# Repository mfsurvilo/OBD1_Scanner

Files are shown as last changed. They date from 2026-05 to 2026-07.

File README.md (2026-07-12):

# OBD1 Scanner

An ESP32-S3 based scanner for OBD-I era ECUs. The device hosts its own Wi-Fi
access point and serves a web console (PWA) straight off the chip — no app to
install — and updates itself over the internet with one button.

- **Firmware:** Arduino/ESP32-S3 (PlatformIO), FreeRTOS tasks, AP+STA Wi-Fi,
  OTA with bootloader rollback.
- **Console (PWA):** served from the device's LittleFS partition; live status
  over WebSocket, Wi-Fi provisioning, one-button update.
- **Delivery:** GitHub Releases hold the images; a static GitHub Pages page
  flashes a device over USB for recovery.

## How the pieces fit together

```
  ┌────────────┐   serves    ┌──────────────┐
  │  firmware  │ ──────────▶ │  PWA console │   (pwa_app/, flashed into LittleFS)
  │  (obd1)    │             │  obd1.local  │
  └─────┬──────┘             └──────┬───────┘
        │ heartbeat + /status       │ "Update now"
        │                           ▼
        │                    GET /update/check   ── picks highest release version
        │                    POST /update/pull   ── pulls firmware.bin + filesystem.bin
        ▼                                            from that release, flashes both
  GitHub Releases  ◀── build_release.sh / release.yml (firmware.bin, filesystem.bin, factory.bin)
        ▲
        │ mirrors factory.bin
  GitHub Pages flasher (firmware_server/flasher/)  ── USB recovery, version dropdown
```

Single sources of truth: `pwa_app/` is the only copy of the console, and
`firmware_server/flasher/versions.json` is the only list of published versions.

## Repo layout

| Path | What it is |
|---|---|
| `firmware/` | PlatformIO project — the device firmware, build/upload scripts, on-target tests |
| `pwa_app/` | The web console served from the device (flashed as the LittleFS image) |
| `firmware_server/` | The static USB-recovery flasher (GitHub Pages) — see its [README](firmware_server/README.md) |
| `tests/` | Host contract tests + hardware-in-the-loop scripts — see its [README](tests/README.md) |
| `protocol/`, `PROTOCOL.md` | OBD-I protocol notes |
| `board/` | KiCad hardware design |
| `developer_tools/` | Misc developer utilities |
| `CHANGELOG.md` | Per-version changes, split into Firmware / PWA sections |

## Quick start

**Flash a board over USB (developer):**
```bash
cd firmware && ./upload.sh          # builds + flashes firmware and the PWA image
```

**Use the device:** join Wi-Fi `OBD1_Scanner` (password `subaru92`), then open
`http://obd1.local/` (or `http://192.168.4.1/`).

## Flashing — three ways

1. **Developer USB** — `firmware/upload.sh` (one combined `pio` command: app + LittleFS).
2. **End-user USB recovery** — the GitHub Pages flasher: pick a version, connect,
   and flash the full image over WebSerial (desktop Chrome/Edge/Opera).
3. **Over-the-air** — the console's **Update now** button (details below).

## Updates (OTA)

The device updates itself over your home Wi-Fi — no file downloads:

1. In the console, save your home Wi-Fi credentials (**Internet update**).
2. Hit **Update now**. The firmware lists the repo's releases, picks the
   **highest version number** (it does *not* rely on GitHub's date-ordered
   `/releases/latest`), and pulls that release's `firmware.bin` (app) and
   `filesystem.bin` (PWA) by explicit tag.
3. It flashes both and reboots. A freshly-updated image boots on probation and
   must self-confirm healthy; if it doesn't, the bootloader rolls back to the
   previous slot.

## Releases

Each release publishes three stable-named assets (the git **tag** carries the
version): `firmware.bin` (app, OTA), `filesystem.bin` (PWA, OTA), and
`factory.bin` (full flash, USB recovery).

To cut a release:
```bash
git tag v0.5 && git push origin v0.5      # release.yml builds + publishes the assets
```
Then add the version to `firmware_server/flasher/versions.json` (newest first,
`latest: true` on it) and push to `master` so the Pages flasher lists it.

Full details — asset layout, the Pages CORS mirror, and the CI workflows — are
in **[`firmware_server/README.md`](firmware_server/README.md)**.

> Tip: cut and push one release tag at a time. Pushing a tag and a `master`
> change together can race the `release` and `pages` workflows.

## Testing

| Layer | What | Runs in CI? |
|---|---|---|
| 0 — host contract (`pytest`) | partition layout, `/status` + `/update/*` surface, image sizes, release-asset & `versions.json` contracts | ✅ |
| 1 — native unit (`pio test -e native`) | pure firmware logic — semver version ordering | ✅ |
| 4–5 — hardware (`hil_roundtrip.py`) | OTA app+fs round-trip, rollback, downgrade matrix | ❌ manual/local |

```bash
python -m pytest tests/ -q          # Layer 0, no hardware (what CI runs)
cd firmware && pio test -e native   # Layer 1, native Unity tests
```

Hardware tests need a real board on the `OBD1_Scanner` AP with USB attached.
Full commands and modes are in **[`tests/README.md`](tests/README.md)**.

## Building

```bash
cd firmware
./upload.sh                # build + USB-flash app + PWA
./build_release.sh         # build + package firmware.bin / filesystem.bin / factory.bin
pio run -e obd1            # just compile the firmware
```
Requires PlatformIO and `esptool` (both in the project `venv/`).

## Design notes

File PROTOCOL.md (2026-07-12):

# OBD1 Scanner — FW ↔ Front-End Protocol

**Protocol version: 1** · Status: living document · Last updated 2026-07-01

This is the single source of truth for the contract between the ESP32 firmware
(`firmware/`) and any front end (`pwa_app/`, `flask_app/`, future UIs). If the
firmware and a UI disagree, they disagree with *this file* — fix the doc and
both sides, don't quietly diverge.

## The value pipeline

```
raw byte ──[FW: hardcoded formula]──▶ engineering ──[app: user calibration]──▶ displayed
             engineering = raw·hw_scale + hw_offset      displayed = engineering·cal_slope + cal_offset
```

- **Hardcoded formula** (`hw_scale`, `hw_offset`) — a fixed property of the SSM1
  protocol per parameter (e.g. `rpm = raw·25`, `°F = raw·1.8 − 147.6`). Baked
  into firmware in `ecu_defs.h` as the `paramMappings[]` table, keyed by name and
  shared across all ECU tables. **Not user-editable.** Source:
  `resources/possible_mapping.txt`. The FW applies this and streams the
  **engineering** value as `params[].value` (and `raw` alongside).
- **User calibration** (`cal_slope` default 1, `cal_offset` default 0) — a trim
  the user applies on top, per parameter. Persisted in FW flash
  (`scaling_config.*`; the NVS keys are still `multiplier`/`offset`). **Applied
  by the app**, not the FW — so tuning is instant and doesn't wear flash. Defaults
  are a no-op, so gauges read correct engineering units out of the box.
- **Poll factor** — the weighted-round-robin poll weight (0 = off). User-editable
  and persisted per param (alongside calibration). On save the FW pushes it to
  the live scheduler; on boot it seeds from the stored value (else a poll-tier
  default).

## Ownership split

| Concern | Owner | Persisted where |
|---|---|---|
| **Hardcoded formula** — `hw_scale`, `hw_offset`, `unit` per param | **Firmware (fixed)** | compiled in `ecu_defs.h` (`paramMappings[]`) |
| **User calibration** — `cal_slope`, `cal_offset` | **User sets; FW stores; app applies** | ESP32 flash (`scaling_config.*`) |
| **Poll factor** — per-param weight (0 = off) | **User sets; FW stores + runs** | ESP32 flash + live scheduler |
| **Presentation** — display label, min/max range, grouping | **Front end** | client-side (localStorage) |

---

## Transports

| Purpose | Transport | Address |
|---|---|---|
| The PWA itself (HTML/CSS/JS/icons) | HTTP GET | `http://<host>/` — served from ESP LittleFS |
| Live data stream (primary) | WebSocket | `ws://<host>:81/` — **root path, no `/ws` suffix** |
| Snapshot poll (fallback) | HTTP GET | `http://<host>:80/data` |
| Calibration / logs / control | HTTP | `http://<host>:80/...` |

`<host>` is `192.168.4.1` (SoftAP `OBD1_Scanner`) or `obd1.local` (mDNS). The
scanner is **AP-only** — the phone connects straight to its access point and
loads the PWA from the device; there is no home-WiFi/station mode.

> ⚠️ **Known drift to fix (2026-07-01):** the current PWA connects to
> `ws://…:<port>/ws` (`pwa_app/js/app.js:378`) and its settings default the port
> to `81` in JS but show `80` in the HTML input (`index.html:262`). Per this
> spec the WS is **port 81, path `/`**. New UI must follow the spec.

---

## Downstream: data snapshot (FW → UI)

The firmware maintains one JSON snapshot and (a) broadcasts it over the
WebSocket whenever it changes, and (b) serves the latest copy at `GET /data`.
On WS connect the current snapshot is sent immediately so the UI populates
without waiting for the next change.

### Schema

```jsonc
{
  "connected": true,          // bool — FW believes it is talking to the ECU
  "timestamp": 123456,        // uint — millis() of last data change (FW uptime)
  "params": [                 // array — one entry per param currently served
    {
      "name":  "EngineSpeed", // string — stable catalog key (see /params)
      "raw":   128,           // number — the ECU byte, before any conversion
      "value": 3200,          // number — ENGINEERING value = raw·hw_scale + hw_offset (FW-applied)
      "unit":  "rpm",         // string — engineering unit
      "time":  123450         // uint   — millis() this param was last read
      // The app shows: value·cal_slope + cal_offset (user calibration, app-applied).
    }
  ],
  "baseHz": 12.5,             // number — est. Hz for a factor-1 param (see polling model)
  "dtc": [                    // array — present only once DTCs are reported
    { "type": "active", "code": "21", "desc": "Coolant temp sensor" }
  ],
  "status": "..."             // string — optional human-readable status line
}
```

Notes:
- `params` is keyed by `name` on both sides. **Never** index by array position.
- `raw` is the ECU value pre-scaling. The UI computes the displayed value as
  `raw * scale + offset` using the calibration for that `name` (from `/params`).
  The wire never carries a pre-scaled `value` — see "Persist ≠ apply" above.
- `params` contains only params whose active `factor > 0`. A param set to 0 is
  absent from the snapshot, not present with a stale value.
- `dtc[].type` ∈ `"active" | "stored"`. `code` is the Subaru 2-digit code as a
  string; `desc` is human text.
- A UI must tolerate unknown `name`s and missing optional keys (`dtc`, `status`).

### Parameter catalog (active ECU: `7232A5` — 1992 UK Legacy EJ22)

These are the `name`s the firmware can currently produce (from `ecu_defs.h`).
Units below are the **firmware default**; the UI owns display range/label.

| name | default unit | poll tier |
|---|---|---|
| EngineSpeed | rpm | fast (50 ms) |
| VehicleSpeed | mph/km/h | fast |
| ThrottlePosition | % | medium (100 ms) |
| O2Average | V | medium |
| IgnitionAdvance | ° BTDC | medium |
| EngineLoad | % | medium |
| InjectorPulseWidth | ms | medium |
| KnockCorrection | ° | medium |
| AFCorrection | % | medium |
| BatteryVoltage | V | slow (250 ms) |
| CoolantTemp | °F/°C | slow |
| AirflowSensor | — | slow |
| ISUDutyValve | % | slow |
| AtmosphericPressure | kPa | vslow (500 ms) |
| InputSwitches | bitfield | vslow |
| IOSwitches | bitfield | vslow |

> The catalog changes with the selected ECU (`#define ECU_*` in `ecu_defs.h`).
> UIs should not hardcode this list — read it from `GET /params` (below).

---

## The parameter record

`GET /params` returns one record per param for the active ECU, combining the
fixed hardcoded mapping with the user-editable calibration:

| field | type | editable? | meaning |
|---|---|---|---|
| `name` | string | no | stable catalog key, e.g. `"EngineSpeed"` |
| `addr` | string | no | ECU memory address, e.g. `"0x1338"` |
| `unit` | string | no | engineering unit, e.g. `"rpm"` |
| `hw_scale` | number | no | hardcoded formula multiplier (`paramMappings[]`) |
| `hw_offset` | number | no | hardcoded formula offset |
| `cal_slope` | number | **yes** (default 1) | user calibration multiplier |
| `cal_offset` | number | **yes** (default 0) | user calibration offset |
| `factor` | integer | **yes** (0 = off) | poll weight (live scheduler value) |

- `POST /scaling` body `{scaling:[{name, multiplier, offset, factor}]}` →
  validates, saves to flash, pushes `factor` to the live scheduler, returns
  `"status":"saved"`. (`multiplier` = `cal_slope`.) Errors →
  `{"status":"error","message":"..."}` with 400/500.
- `GET /scaling` → persisted calibration records (per `ScalingConfig.toJson`).
- CORS: `Access-Control-Allow-Origin: *`; preflight `OPTIONS /scaling` → 204.

> ⚠️ **Scope note:** `addr`/`name`/`hw_*` are compile-time `const` in
> `ecu_defs.h`; only `cal_slope`/`cal_offset`/`factor` are editable/persisted.
> Making `addr`/`name` runtime-editable is a later expansion.

### ECU Calibration page (under the home menu)

Shows every param with its hardcoded formula (read-only) plus editable
`cal_slope`, `cal_offset`, and `factor`. **Save** issues one `POST /scaling`
(the only screen that writes to flash) and updates the live gauges immediately.

---

## Logs & diagnostics (HTTP)

| Endpoint | Returns |
|---|---|
| `GET /log` | `{ "ram": "<log text>", "ramUsed": <int> }` (newlines escaped) |
| `GET /log/ram` | RAM log as `text/plain` |
| `GET /log/ram/clear` | `{ "status":"ram_cleared" }` |
| `GET /log/flash` | flash log as `text/plain` |
| `GET /log/flash/clear` | `{ "status":"flash_cleared" }` |

---

## Polling model (factors, not periods)

Each param has an integer **polling factor** that is a *relative weight*, not a
period:

- `factor = 0` → param is **off** (not sampled, absent from snapshot).
- `factor = 1` → the baseline rate.
- `factor = n` → sampled **n× as often** as a factor-1 param.

The ECU link runs at a fixed physical throughput. Let **R** = reads/second the
link can sustain (a function of baud rate + per-read response latency; the FW
knows it best). The FW polls in a weighted round-robin, so with active factors
`f₁…fₖ`:

```
baseHz = R / Σ fᵢ            # rate of a factor-1 param
paramHz(i) = fᵢ · baseHz     # rate of param i
```

So adding params or raising factors *lowers* `baseHz` — the UI surfaces the
tradeoff by displaying `baseHz` (see "base polling frequency" in the UI). The FW
reports `baseHz` in every snapshot; it also reports `R` once (in `/params`, as
`readsPerSec`) so the UI can **estimate `baseHz` locally and instantly** as the
user changes views, before the subscription round-trips.

**Startup state:** on boot every factor is `0` — nothing is polled. Polling
begins only when a connected UI sends a subscription.

**View presets (UI-side):** each view maps to a set of factors; entering the
view sends that subscription, so only what's on screen is sampled and it polls
fast. Example — *General Vehicle Data*:

```jsonc
{ "EngineSpeed": 3, "VehicleSpeed": 3, "CoolantTemp": 1,
  "BatteryVoltage": 1, "IntakeAirTemp": 1 }   // everything else → 0
```

*(Assumes IntakeAirTemp = 1; confirm — your note listed 5 params but 4 factors.)*

---

## Upstream: front-end drives the active set  — ⚠️ PROPOSED, not yet implemented

Today the WebSocket is **receive-only** (`wifi_server.cpp:247`). Per-param poll
factors are currently set via `POST /scaling` (persisted, applied to the live
scheduler) — good enough for the calibration page. The WS `subscribe` below is a
**future** optimization for fast, transient, view-driven switching (enter a view
→ poll only its params, no flash write). It is the proposed design — **build the
UI against it via the mock, then implement it in firmware.**

### 1. Discover the catalog — ✅ implemented (`GET /params`)

```jsonc
GET /params  →
{
  "ecu": "7232A5",
  "name": "1992 UK Legacy EJ22",
  "params": [
    { "name":"EngineSpeed", "addr":"0x1338", "unit":"rpm",
      "hw_scale":25.0, "hw_offset":0.0,     // hardcoded (read-only)
      "cal_slope":1.0, "cal_offset":0.0,    // user calibration (editable)
      "factor":10 }                          // live poll weight (editable via POST /scaling)
    // ...one record per catalog entry
  ]
}
```

### 2. Subscribe (UI → FW, WebSocket text frame)

```jsonc
{ "cmd": "subscribe",
  "factors": { "EngineSpeed": 3, "VehicleSpeed": 3, "CoolantTemp": 1 } }
```

- Names present set that factor; **names absent are set to 0** (a subscribe is
  the complete active set, not a delta). Send `{}` to stop all polling.
- Other proposed commands: `{ "cmd":"clearDTC" }`, `{ "cmd":"ping" }`.
- Unknown `cmd` ⇒ FW ignores and (optionally) logs.

### 3. Global scope; FW acknowledges

**Decided (2026-07-01):**

- **Scope is global, not per-connection.** One active set for the whole device;
  the most recent `subscribe` wins for all ≤4 clients. A late-joining client
  sees the current set until it sends its own. UIs must treat the active set as
  **shared state** — a second phone's subscribe changes what the first receives.
- **The FW confirms every subscription** with an ACK frame:

  ```jsonc
  { "ack": "subscribe",
    "active": { "EngineSpeed": 3, "VehicleSpeed": 3, "CoolantTemp": 1 },
    "baseHz": 8.9,             // recomputed for the new active set
    "rejected": [ ]            // names not in the current ECU catalog
  }
  ```

  The UI reconciles against `active`/`rejected` rather than assuming its request
  applied verbatim (a `name` may be unknown to the current ECU).

---

## Versioning

- The snapshot **should** carry the protocol version once the upstream channel
  lands, e.g. add `"proto": 1` at the top level of `/data` and the WS snapshot.
- Bump the version on any breaking change to the snapshot schema. Additive
  fields (new optional keys) do **not** bump the version; removals/renames do.

---

## Machine-readable schema & conformance

The shapes above are also defined as JSON Schema and enforced at runtime:

- **`protocol/schema.json`** — canonical `$defs` for `Snapshot`, `ParamSample`,
  `Dtc`, `ParamsResponse`, `ParamDescriptor`, `SubscribeCommand`, `SubscribeAck`.
  This file and this doc must agree; changing one means changing the other.
- **`protocol/validate.js`** — dependency-free ES-module validator (no build
  step). `import { validateSnapshot } from '../protocol/validate.js'`.

Any front-end mock transport (e.g. `pwa_app`'s `simulate*` functions, or a
future `MockTransport`) MUST emit messages that pass these validators — same
keys, same `params[]` keyed by `name`. Both `MockTransport` and
`WebSocketTransport` should run every inbound snapshot through `validateSnapshot`
in dev, so the mock **cannot** drift from the real shape. If the UI works
against the validated mock, swapping in the real WebSocket is a transport change
only, never a data-shape change. That equivalence is the whole point of this
layer.

Additive fields are allowed (validators don't reject unknown keys) — matching
the versioning rule. Only removals/renames are breaking.

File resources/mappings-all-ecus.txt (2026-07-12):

;;;;;;;;;;;;;;;;;;;;;;;;;;;;;;;;;;;;;;;;;;;;;;;;;;;;;;;;;;;;;;;;;;;;;;;;;;;;;;;;;;;;;;;
; SelectMonitor.ini file version 1.1.0 - July 22, 2008
;
; NOTE: Requires SelectMonitor.exe version 1.0.1 or higher
;;;;;;;;;;;;;;;;;;;;;;;;;;;;;;;;;;;;;;;;;;;;;;;;;;;;;;;;;;;;;;;;;;;;;;;;;;;;;;;;;;;;;;;

;;;;;;;;;;;;;;;;;;;;;;;;;;;;;;;;;;;;;;;;;;;;;;;;;;;;;;;;;;;;;;;;;;;;;;;;;;;;;;;;;;;;;;;
; General application options
;;;;;;;;;;;;;;;;;;;;;;;;;;;;;;;;;;;;;;;;;;;;;;;;;;;;;;;;;;;;;;;;;;;;;;;;;;;;;;;;;;;;;;;
[Options]
;Comm Port number to use (i.e. which serial port)
CommPort=1

;AutoStart=0 Do not automatically start scanning
;AutoStart=1 Automatically start scanning when program starts
AutoStart=0

;GraphicMode=0 Start program in Normal View
;GraphicMode=1 Start program in graphics mode also issues AutoStart=1
GraphicMode=0

;Fahrenheit=1 Use Fahrenheit
;Fahrenheit=0 Use Celsius
Fahrenheit=1

;MPH=1 Use miles per hour
;MPH=0 Use Kilometers per hour
MPH=1

;Pressure Units
;0=PSI
;1=Bar
;2=mmHg
;3=inHg
AtmosphericPressureUnits=1
ManifoldPressureUnits=2

;Data Logging to the SelectMonitor.log and SelectMonitorDump.log file (1=Yes,0=No)
Logging=1
;Log the RAW 8 bit data from the ECU or the computed display value
LogRawData=0
;Overwrite or append the previous log file when starting
LogOverwrite=1
;Field separator character, 9 is a tab character and works well for opening the log file in excel
LogFieldSeparator=9

;;;;;;;;;;;;;;;;;;;;;;;;;;;;;;;;;;;;;;;;;;;;;;;;;;;;;;;;;;;;;;;;;;;;;;;;;;;;;;;;;;;;;;;
; The Default ROM ID used when no ROM ID detected
;;;;;;;;;;;;;;;;;;;;;;;;;;;;;;;;;;;;;;;;;;;;;;;;;;;;;;;;;;;;;;;;;;;;;;;;;;;;;;;;;;;;;;;
[null]
;;;;;;;;;;;;;;;;;;;;;;;;;;;;;;;;;;;;;;;;;;;;;;;
;Parameter "Address" values are in HEXadecimal
;as displayed in the SelectMonitorDump utility
;;;;;;;;;;;;;;;;;;;;;;;;;;;;;;;;;;;;;;;;;;;;;;;
BatteryVoltageAddress=1335
VehicleSpeedAddress=1336
EngineSpeedAddress=1338
CoolantTempAddress=1337
IgnitionAdvanceAddress=1053
AirflowSensorAddress=1308
EngineLoadAddress=1305
ThrottlePositionAddress=1329
InjectorPulseWidthAddress=1306
ISUDutyValveAddress=1307
O2AverageAddress=1309
O2MinimumAddress=130A
O2MaximumAddress=130B
KnockCorrectionAddress=1054
AFCorrectionAddress=1055
AtmosphericPressureAddress=1340
ManifoldPressureAddress=1342
BoostSolenoidDutyCycleAddress=1341
;;;;;;;;;;;;;;;;;;;;;;;;;;;;;;;;;;;;;;;;
;Parameter "Mode" values have 3 options
;2=Parameter Enabled and not Scanned
;1=Parameter Enabled and Scanned
;0=Parameter Disabled
;-1=Parameter Invisible
;;;;;;;;;;;;;;;;;;;;;;;;;;;;;;;;;;;;;;;;
BatteryVoltageMode=1
VehicleSpeedMode=1
EngineSpeedMode=1
CoolantTempMode=1
IgnitionAdvanceMode=1
AirflowSensorMode=1
EngineLoadMode=1
ThrottlePositionMode=1
InjectorPulseWidthMode=1
ISUDutyValveMode=1
O2AverageMode=1
O2MinimumMode=1
O2MaximumMode=1
KnockCorrectionMode=1
AFCorrectionMode=1
AtmosphericPressureMode=1
ManifoldPressureMode=1
BoostSolenoidDutyCycleMode=1
;;;;;;;;;;;;;;;;;;;;;;;;;;;;;;;;;;;;;;;;;;;;;;;;;;;;;;;;;;;;;;;;;;;;;;;;;;;;;;;;;;;;;;;

;;;;;;;;;;;;;;;;;;;;;;;;;;;;;;;;;;;;;;;;;;;;;;;;;;;;;;;;;;;;;;;;;;;;;;;;;;;;;;;;;;;;;;;
; ROM ID 0x744014: 1995 JDM WRX STi Version 2
;
;Updated: Nov 3rd 2006
;
;Note: I don't think this ECU has O2Maximum and O2Minimum parameters. All other
; parameters have been verified unless otherwise noted below.
;
;Information contributed by Kevin Frank <freerock@vwrx.com>
;
;Note: ROM ID's can be specified as 16 or 24 bits (i.e. 7440 or 744014)
;;;;;;;;;;;;;;;;;;;;;;;;;;;;;;;;;;;;;;;;;;;;;;;;;;;;;;;;;;;;;;;;;;;;;;;;;;;;;;;;;;;;;;;
[744014]
Name=1995 JDM WRX STi Version 2
;;;;;;;;;;;;;;;;;;;;;;;;;;;;;;;;;;;;;;;;;;;;;;;
;Parameter "Address" values are in HEXadecimal
;as displayed in the SelectMonitorDump utility
;;;;;;;;;;;;;;;;;;;;;;;;;;;;;;;;;;;;;;;;;;;;;;;
BatteryVoltageAddress=1335
; VehicleSpeed never changes, could be my speed sensor?
VehicleSpeedAddress=1336
EngineSpeedAddress=1338
CoolantTempAddress=1337
IgnitionAdvanceAddress=1053
AirflowSensorAddress=1308
EngineLoadAddress=1305
ThrottlePositionAddress=1329
InjectorPulseWidthAddress=1306
ISUDutyValveAddress=1307
O2AverageAddress=130A
O2MinimumAddress=0
O2MaximumAddress=0
KnockCorrectionAddress=1054
; AFCorrection never changes, must be a different address?
AFCorrectionAddress=1055
AtmosphericPressureAddress=1340
ManifoldPressureAddress=1341
; BoostSolenoidDutyCycle changes very frequently, decreases on accel, increases on deaccel, probably not correct address?
BoostSolenoidDutyCycleAddress=1344
;;;;;;;;;;;;;;;;;;;;;;;;;;;;;;;;;;;;;;;;
;Parameter "Mode" values have 3 options
;2=Parameter Enabled and not Scanned
;1=Parameter Enabled and Scanned
;0=Parameter Disabled
;-1=Parameter Invisible
;;;;;;;;;;;;;;;;;;;;;;;;;;;;;;;;;;;;;;;;
BatteryVoltageMode=1
VehicleSpeedMode=1
EngineSpeedMode=1
CoolantTempMode=1
IgnitionAdvanceMode=1
AirflowSensorMode=1
EngineLoadMode=1
ThrottlePositionMode=1
InjectorPulseWidthMode=1
ISUDutyValveMode=1
O2AverageMode=1
O2MinimumMode=-1
O2MaximumMode=-1
KnockCorrectionMode=1
AFCorrectionMode=1
AtmosphericPressureMode=1
ManifoldPressureMode=1
BoostSolenoidDutyCycleMode=1
;;;;;;;;;;;;;;;;;;;;;;;;;;;;;;;;;;;;;;;;;;;;;;;;;;;;;;;;;;;;;;;;;;;;;;;;;;;;;;;;;;;;;;;

;;;;;;;;;;;;;;;;;;;;;;;;;;;;;;;;;;;;;;;;;;;;;;;;;;;;;;;;;;;;;;;;;;;;;;;;;;;;;;;;;;;;;;;
; ROM ID 0x7136XX: 1991 Turbo
;
;Note: Early turbo - UNTESTED 
;Information contributed by Vikash Ravi Goel <v@graphics.cornell.edu>
;;;;;;;;;;;;;;;;;;;;;;;;;;;;;;;;;;;;;;;;;;;;;;;;;;;;;;;;;;;;;;;;;;;;;;;;;;;;;;;;;;;;;;;
[7136]
Name=1991 Turbo
BatteryVoltageAddress=1404
VehicleSpeedAddress=154B
EngineSpeedAddress=140B
CoolantTempAddress=1405
IgnitionAdvanceAddress=1489
AirflowSensorAddress=1400
EngineLoadAddress=1414
ThrottlePositionAddress=1487
InjectorPulseWidthAddress=142A
ISUDutyValveAddress=158A
O2AverageAddress=1403
O2MinimumAddress=0
O2MaximumAddress=0
KnockCorrectionAddress=1530
AFCorrectionAddress=1488
AtmosphericPressureAddress=1516
ManifoldPressureAddress=00BE
BoostSolenoidDutyCycleAddress=144D
;;;;;;;;;;;;;;;;;;;;;;;;;;;;;;;;;;;;;;;;
;Other Known Addresses for this ECU
;ZeroedThrottleAddress=1453
;InputSwitchesAddress=15A8	; [IG.AT.!UD.!RM.xx.!NT.!PK.FC]
;IOSwitchesAddress=15A9		; [ID.AC.AR.RF.FP.CN.KS.BR]
;;;;;;;;;;;;;;;;;;;;;;;;;;;;;;;;;;;;;;;;
BatteryVoltageMode=1
VehicleSpeedMode=1
EngineSpeedMode=1
CoolantTempMode=1
IgnitionAdvanceMode=1
AirflowSensorMode=1
EngineLoadMode=1
ThrottlePositionMode=1
InjectorPulseWidthMode=1
ISUDutyValveMode=1
O2AverageMode=1
O2MinimumMode=-1
O2MaximumMode=-1
KnockCorrectionMode=1
AFCorrectionMode=1
AtmosphericPressureMode=1
ManifoldPressureMode=1
BoostSolenoidDutyCycleMode=1
;;;;;;;;;;;;;;;;;;;;;;;;;;;;;;;;;;;;;;;;;;;;;;;;;;;;;;;;;;;;;;;;;;;;;;;;;;;;;;;;;;;;;;;

;;;;;;;;;;;;;;;;;;;;;;;;;;;;;;;;;;;;;;;;;;;;;;;;;;;;;;;;;;;;;;;;;;;;;;;;;;;;;;;;;;;;;;;
; ROM ID 0x7236XX: 1991-1994 Turbo
;
;Note: Turbo - UNTESTED
;Information contributed by Vikash Ravi Goel <v@graphics.cornell.edu>
;;;;;;;;;;;;;;;;;;;;;;;;;;;;;;;;;;;;;;;;;;;;;;;;;;;;;;;;;;;;;;;;;;;;;;;;;;;;;;;;;;;;;;;
[7236]
Name=1991-1994 Turbo
BatteryVoltageAddress=1404
VehicleSpeedAddress=154B
EngineSpeedAddress=140B
CoolantTempAddress=1405
IgnitionAdvanceAddress=1489
AirflowSensorAddress=1400
EngineLoadAddress=1414
ThrottlePositionAddress=1487
InjectorPulseWidthAddress=15F0
ISUDutyValveAddress=158A
O2AverageAddress=1403
O2MinimumAddress=0
O2MaximumAddress=0
KnockCorrectionAddress=1530
AFCorrectionAddress=1488
AtmosphericPressureAddress=1516
ManifoldPressureAddress=00BE
BoostSolenoidDutyCycleAddress=144D
;;;;;;;;;;;;;;;;;;;;;;;;;;;;;;;;;;;;;;;;
;Other Known Addresses for this ECU
;ZeroedThrottleAddress=1453
;InputSwitchesAddress=15A8	; [IG.AT.!UD.!RM.xx.!NT.!PK.FC]
;IOSwitchesAddress=15A9		; [ID.AC.AR.RF.FP.CN.KS.BR]
;;;;;;;;;;;;;;;;;;;;;;;;;;;;;;;;;;;;;;;;
BatteryVoltageMode=1
VehicleSpeedMode=1
EngineSpeedMode=1
CoolantTempMode=1
IgnitionAdvanceMode=1
AirflowSensorMode=1
EngineLoadMode=1
ThrottlePositionMode=1
InjectorPulseWidthMode=1
ISUDutyValveMode=1
O2AverageMode=1
O2MinimumMode=-1
O2MaximumMode=-1
KnockCorrectionMode=1
AFCorrectionMode=1
AtmosphericPressureMode=1
ManifoldPressureMode=1
BoostSolenoidDutyCycleMode=1
;;;;;;;;;;;;;;;;;;;;;;;;;;;;;;;;;;;;;;;;;;;;;;;;;;;;;;;;;;;;;;;;;;;;;;;;;;;;;;;;;;;;;;;

;;;;;;;;;;;;;;;;;;;;;;;;;;;;;;;;;;;;;;;;;;;;;;;;;;;;;;;;;;;;;;;;;;;;;;;;;;;;;;;;;;;;;;;
; ROM ID 0x7031XX: 1990-1991 5MT NA
;
;Note: Hitachi - UNTESTED
;Information contributed by Vikash Ravi Goel <v@graphics.cornell.edu>
;;;;;;;;;;;;;;;;;;;;;;;;;;;;;;;;;;;;;;;;;;;;;;;;;;;;;;;;;;;;;;;;;;;;;;;;;;;;;;;;;;;;;;;
[7031]
Name=1990-1991 5MT NA
BatteryVoltageAddress=1404
VehicleSpeedAddress=154B
EngineSpeedAddress=140B
CoolantTempAddress=1405
IgnitionAdvanceAddress=1489
AirflowSensorAddress=1400
EngineLoadAddress=1414
ThrottlePositionAddress=1487
InjectorPulseWidthAddress=142A
ISUDutyValveAddress=158A
O2AverageAddress=1403
O2MinimumAddress=0
O2MaximumAddress=0
KnockCorrectionAddress=1530
AFCorrectionAddress=1488
AtmosphericPressureAddress=140A
ManifoldPressureAddress=0
BoostSolenoidDutyCycleAddress=0
;;;;;;;;;;;;;;;;;;;;;;;;;;;;;;;;;;;;;;;;
;Other Known Addresses for this ECU
;ZeroedThrottleAddress=1453
;InputSwitchesAddress=15A8	; [IG.AT.!UD.!RM.xx.!NT.PK.FC]
;IOSwitchesAddress=15A9		; [ID.AC.AR.RF.FP.CN.KS.xx]
;;;;;;;;;;;;;;;;;;;;;;;;;;;;;;;;;;;;;;;;
BatteryVoltageMode=1
VehicleSpeedMode=1
EngineSpeedMode=1
CoolantTempMode=1
IgnitionAdvanceMode=1
AirflowSensorMode=1
EngineLoadMode=1
ThrottlePositionMode=1
InjectorPulseWidthMode=1
ISUDutyValveMode=1
O2AverageMode=1
O2MinimumMode=-1
O2MaximumMode=-1
KnockCorrectionMode=1
AFCorrectionMode=1
AtmosphericPressureMode=1
ManifoldPressureMode=-1
BoostSolenoidDutyCycleMode=-1
;;;;;;;;;;;;;;;;;;;;;;;;;;;;;;;;;;;;;;;;;;;;;;;;;;;;;;;;;;;;;;;;;;;;;;;;;;;;;;;;;;;;;;;

;;;;;;;;;;;;;;;;;;;;;;;;;;;;;;;;;;;;;;;;;;;;;;;;;;;;;;;;;;;;;;;;;;;;;;;;;;;;;;;;;;;;;;;
; ROM ID 0x7032XX: 1990-1991 4EAT NA
;
;Note: JECS 1 - UNTESTED
;Information contributed by Vikash Ravi Goel <v@graphics.cornell.edu>
;;;;;;;;;;;;;;;;;;;;;;;;;;;;;;;;;;;;;;;;;;;;;;;;;;;;;;;;;;;;;;;;;;;;;;;;;;;;;;;;;;;;;;;
[7032]
Name=1990-1991 4EAT NA
BatteryVoltageAddress=4780
VehicleSpeedAddress=4781
EngineSpeedAddress=43BC
CoolantTempAddress=4782
IgnitionAdvanceAddress=43C8
AirflowSensorAddress=43AD
EngineLoadAddress=43AA
ThrottlePositionAddress=4784
InjectorPulseWidthAddress=43AB
ISUDutyValveAddress=43E3
O2AverageAddress=43CF
O2MinimumAddress=0
O2MaximumAddress=0
KnockCorrectionAddress=440D
AFCorrectionAddress=43CE
AtmosphericPressureAddress=4787
ManifoldPressureAddress=0
BoostSolenoidDutyCycleAddress=0
;;;;;;;;;;;;;;;;;;;;;;;;;;;;;;;;;;;;;;;;
;Other Known Addresses for this ECU
;InputSwitchesAddress=4789	; [IG.AT.UD.RM.xx.NT.PK.FC]
;IOSwitchesAddress=478A
;;;;;;;;;;;;;;;;;;;;;;;;;;;;;;;;;;;;;;;;
BatteryVoltageMode=1
VehicleSpeedMode=1
EngineSpeedMode=1
CoolantTempMode=1
IgnitionAdvanceMode=1
AirflowSensorMode=1
EngineLoadMode=1
ThrottlePositionMode=1
InjectorPulseWidthMode=1
ISUDutyValveMode=1
O2AverageMode=1
O2MinimumMode=-1
O2MaximumMode=-1
KnockCorrectionMode=1
AFCorrectionMode=1
AtmosphericPressureMode=1
ManifoldPressureMode=-1
BoostSolenoidDutyCycleMode=-1
;;;;;;;;;;;;;;;;;;;;;;;;;;;;;;;;;;;;;;;;;;;;;;;;;;;;;;;;;;;;;;;;;;;;;;;;;;;;;;;;;;;;;;;

;;;;;;;;;;;;;;;;;;;;;;;;;;;;;;;;;;;;;;;;;;;;;;;;;;;;;;;;;;;;;;;;;;;;;;;;;;;;;;;;;;;;;;;
; ROM ID 0x7232XX: 1992 NA
;
;Note: JECS 2 - UNTESTED
;Information contributed by Vikash Ravi Goel <v@graphics.cornell.edu>
;;;;;;;;;;;;;;;;;;;;;;;;;;;;;;;;;;;;;;;;;;;;;;;;;;;;;;;;;;;;;;;;;;;;;;;;;;;;;;;;;;;;;;;
[7232]
Name=1992 NA
BatteryVoltageAddress=1335
VehicleSpeedAddress=1336
EngineSpeedAddress=1338
CoolantTempAddress=1337
IgnitionAdvanceAddress=1323
AirflowSensorAddress=1307
EngineLoadAddress=1305
ThrottlePositionAddress=1329
InjectorPulseWidthAddress=1306
ISUDutyValveAddress=1314
O2AverageAddress=1310
O2MinimumAddress=0
O2MaximumAddress=0
KnockCorrectionAddress=1328
AFCorrectionAddress=133E
AtmosphericPressureAddress=1340
ManifoldPressureAddress=0
BoostSolenoidDutyCycleAddress=0
;;;;;;;;;;;;;;;;;;;;;;;;;;;;;;;;;;;;;;;;
;Other Known Addresses for this ECU
;InputSwitchesAddress=1343	; [IG.AT.UD.RM.xx.!NT.PK.FC]
;IOSwitchesAddress=1344
;;;;;;;;;;;;;;;;;;;;;;;;;;;;;;;;;;;;;;;;
BatteryVoltageMode=1
VehicleSpeedMode=1
EngineSpeedMode=1
CoolantTempMode=1
IgnitionAdvanceMode=1
AirflowSensorMode=1
EngineLoadMode=1
ThrottlePositionMode=1
InjectorPulseWidthMode=1
ISUDutyValveMode=1
O2AverageMode=1
O2MinimumMode=-1
O2MaximumMode=-1
KnockCorrectionMode=1
AFCorrectionMode=1
AtmosphericPressureMode=1
ManifoldPressureMode=-1
BoostSolenoidDutyCycleMode=-1
;;;;;;;;;;;;;;;;;;;;;;;;;;;;;;;;;;;;;;;;;;;;;;;;;;;;;;;;;;;;;;;;;;;;;;;;;;;;;;;;;;;;;;;

;;;;;;;;;;;;;;;;;;;;;;;;;;;;;;;;;;;;;;;;;;;;;;;;;;;;;;;;;;;;;;;;;;;;;;;;;;;;;;;;;;;;;;;
; ROM ID 0x7332XX: 1993-1994 NA
;
;Note: JECS 3 - UNTESTED
;Information contributed by Vikash Ravi Goel <v@graphics.cornell.edu>
;;;;;;;;;;;;;;;;;;;;;;;;;;;;;;;;;;;;;;;;;;;;;;;;;;;;;;;;;;;;;;;;;;;;;;;;;;;;;;;;;;;;;;;
[7332]
Name=1993-1994 NA
BatteryVoltageAddress=1335
VehicleSpeedAddress=1336
EngineSpeedAddress=1338
CoolantTempAddress=1337
IgnitionAdvanceAddress=1323
AirflowSensorAddress=1307
EngineLoadAddress=1305
ThrottlePositionAddress=1329
InjectorPulseWidthAddress=1306
ISUDutyValveAddress=1314
O2AverageAddress=1310
O2MinimumAddress=0
O2MaximumAddress=0
KnockCorrectionAddress=1328
AFCorrectionAddress=133E
AtmosphericPressureAddress=0
ManifoldPressureAddress=0
BoostSolenoidDutyCycleAddress=0
;;;;;;;;;;;;;;;;;;;;;;;;;;;;;;;;;;;;;;;;
;Other Known Addresses for this ECU
;InputSwitchesAddress=1343	; [IG.AT.UD.RM.xx.!NT.PK.FC]
;IOSwitchesAddress=1344
;;;;;;;;;;;;;;;;;;;;;;;;;;;;;;;;;;;;;;;;
BatteryVoltageMode=1
VehicleSpeedMode=1
EngineSpeedMode=1
CoolantTempMode=1
IgnitionAdvanceMode=1
AirflowSensorMode=1
EngineLoadMode=1
ThrottlePositionMode=1
InjectorPulseWidthMode=1
ISUDutyValveMode=1
O2AverageMode=1
O2MinimumMode=-1
O2MaximumMode=-1
KnockCorrectionMode=1
AFCorrectionMode=1
AtmosphericPressureMode=-1
ManifoldPressureMode=-1
BoostSolenoidDutyCycleMode=-1
;;;;;;;;;;;;;;;;;;;;;;;;;;;;;;;;;;;;;;;;;;;;;;;;;;;;;;;;;;;;;;;;;;;;;;;;;;;;;;;;;;;;;;;

;;;;;;;;;;;;;;;;;;;;;;;;;;;;;;;;;;;;;;;;;;;;;;;;;;;;;;;;;;;;;;;;;;;;;;;;;;;;;;;;;;;;;;;
; ROM ID 0xA30117: 1999 European Forester with EJ20 non-Turbo engine
;
;Note: Contributed and tested by Alexey K. Bybnov <bybnov@marvel.ru>
;;;;;;;;;;;;;;;;;;;;;;;;;;;;;;;;;;;;;;;;;;;;;;;;;;;;;;;;;;;;;;;;;;;;;;;;;;;;;;;;;;;;;;;
[A30117]
Name=1999 Forester EURO 2.0
BatteryVoltageAddress=0007
VehicleSpeedAddress=0008
EngineSpeedAddress=0009
CoolantTempAddress=000A
IgnitionAdvanceAddress=000B
AirflowSensorAddress=000C
EngineLoadAddress=000D
ThrottlePositionAddress=000F
InjectorPulseWidthAddress=0010
ISUDutyValveAddress=0011
O2AverageAddress=0012
O2MinimumAddress=0013
O2MaximumAddress=0014
KnockCorrectionAddress=0015
AFCorrectionAddress=001C
AtmosphericPressureAddress=001F
ManifoldPressureAddress=0020
BoostSolenoidDutyCycleAddress=0022
BatteryVoltageMode=1
VehicleSpeedMode=1
EngineSpeedMode=1
CoolantTempMode=1
IgnitionAdvanceMode=1
AirflowSensorMode=1
EngineLoadMode=1
ThrottlePositionMode=1
InjectorPulseWidthMode=1
ISUDutyValveMode=1
O2AverageMode=1
O2MinimumMode=1
O2MaximumMode=1
KnockCorrectionMode=1
AFCorrectionMode=1
AtmosphericPressureMode=1
ManifoldPressureMode=1
BoostSolenoidDutyCycleMode=-1
;;;;;;;;;;;;;;;;;;;;;;;;;;;;;;;;;;;;;;;;;;;;;;;;;;;;;;;;;;;;;;;;;;;;;;;;;;;;;;;;;;;;;;;

;;;;;;;;;;;;;;;;;;;;;;;;;;;;;;;;;;;;;;;;;;;;;;;;;;;;;;;;;;;;;;;;;;;;;;;;;;;;;;;;;;;;;;;
; ROM ID 0xA30113: 1997 Impreza GT sport wagon, EDM, 155kW
;
; Note: 155kW "classic" Impreza, tested
; Information contributed by HaBa <haba_cpu@hotmail.com>
;
; Also: Same ROM ID used in a 1998 Portuguese Impreza GT 4WD with EJ20 Turbo engine
; Contributed and tested by Paulo Barata <paulo.b.barata@clix.pt>
;;;;;;;;;;;;;;;;;;;;;;;;;;;;;;;;;;;;;;;;;;;;;;;;;;;;;;;;;;;;;;;;;;;;;;;;;;;;;;;;;;;;;;;
[A30113]
Name=1997-8 GT sport wagon EDM
BatteryVoltageAddress=0007
VehicleSpeedAddress=0008
EngineSpeedAddress=0009
CoolantTempAddress=000A
IgnitionAdvanceAddress=000B
AirflowSensorAddress=000C
EngineLoadAddress=000D
ThrottlePositionAddress=000F
InjectorPulseWidthAddress=0010
ISUDutyValveAddress=0011
O2AverageAddress=0012
O2MinimumAddress=0013
O2MaximumAddress=0014
KnockCorrectionAddress=0015
AFCorrectionAddress=001C
AtmosphericPressureAddress=001F
ManifoldPressureAddress=0020
BoostSolenoidDutyCycleAddress=0022
BatteryVoltageMode=1
VehicleSpeedMode=1
EngineSpeedMode=1
CoolantTempMode=1
IgnitionAdvanceMode=1
AirflowSensorMode=1
EngineLoadMode=1
ThrottlePositionMode=1
InjectorPulseWidthMode=1
ISUDutyValveMode=1
O2AverageMode=1
O2MinimumMode=1
O2MaximumMode=1
KnockCorrectionMode=1
AFCorrectionMode=1
AtmosphericPressureMode=1
ManifoldPressureMode=1
BoostSolenoidDutyCycleMode=1
;;;;;;;;;;;;;;;;;;;;;;;;;;;;;;;;;;;;;;;;;;;;;;;;;;;;;;;;;;;;;;;;;;;;;;;;;;;;;;;;;;;;;;;

;;;;;;;;;;;;;;;;;;;;;;;;;;;;;;;;;;;;;;;;;;;;;;;;;;;;;;;;;;;;;;;;;;;;;;;;;;;;;;;;;;;;;;;
; ROM ID 0x7225xx: 1992 SVX
;
;Information contributed by Phil Skuse <phil@alcyone.org.uk>
;;;;;;;;;;;;;;;;;;;;;;;;;;;;;;;;;;;;;;;;;;;;;;;;;;;;;;;;;;;;;;;;;;;;;;;;;;;;;;;;;;;;;;;
[7225]
Name=1992 SVX
BatteryVoltageAddress=12A2
VehicleSpeedAddress=12A4
EngineSpeedAddress=1290
CoolantTempAddress=1185
IgnitionAdvanceAddress=10A2
AirflowSensorAddress=1283
EngineLoadAddress=1282
ThrottlePositionAddress=128C
InjectorPulseWidthAddress=0
ISUDutyValveAddress=129D
O2AverageAddress=1291
O2MinimumAddress=12B1
O2MaximumAddress=12B0
KnockCorrectionAddress=12A7
AFCorrectionAddress=12AD
AtmosphericPressureAddress=0
ManifoldPressureAddress=0
BoostSolenoidDutyCycleAddress=0
;;;;;;;;;;;;;;;;;;;;;;;;;;;;;;;;;;;;;;;;;;;;;;;;;;;;;;;;;;
; O2 parameters are for the Right O2 Sensor              ;
; Use 1292,12B3,12B2 for the Left O2 Sensor              ;
; O2Average is not an average, it is the current reading ;
;;;;;;;;;;;;;;;;;;;;;;;;;;;;;;;;;;;;;;;;;;;;;;;;;;;;;;;;;;
BatteryVoltageMode=1
VehicleSpeedMode=1
EngineSpeedMode=1
CoolantTempMode=1
IgnitionAdvanceMode=1
AirflowSensorMode=1
EngineLoadMode=1
ThrottlePositionMode=1
InjectorPulseWidthMode=0
ISUDutyValveMode=1
O2AverageMode=1
O2MinimumMode=-1
O2MaximumMode=-1
KnockCorrectionMode=1
AFCorrectionMode=1
AtmosphericPressureMode=0
ManifoldPressureMode=-1
BoostSolenoidDutyCycleMode=-1
;;;;;;;;;;;;;;;;;;;;;;;;;;;;;;;;;;;;;;;;;;;;;;;;;;;;;;;;;;;;;;;;;;;;;;;;;;;;;;;;;;;;;;;

;;;;;;;;;;;;;;;;;;;;;;;;;;;;;;;;;;;;;;;;;;;;;;;;;;;;;;;;;;;;;;;;;;;;;;;;;;;;;;;;;;;;;;;
; ROM ID 0x7425xx: 1994 SVX
;
;Information contributed by Phil Skuse <phil@alcyone.org.uk>
;;;;;;;;;;;;;;;;;;;;;;;;;;;;;;;;;;;;;;;;;;;;;;;;;;;;;;;;;;;;;;;;;;;;;;;;;;;;;;;;;;;;;;;
[7425]
Name=1994 SVX
BatteryVoltageAddress=12A2
VehicleSpeedAddress=12A4
EngineSpeedAddress=1290
CoolantTempAddress=1185
IgnitionAdvanceAddress=10A2
AirflowSensorAddress=1283
EngineLoadAddress=1282
ThrottlePositionAddress=128C
InjectorPulseWidthAddress=0
ISUDutyValveAddress=129D
O2AverageAddress=1291
O2MinimumAddress=12B1
O2MaximumAddress=12B0
KnockCorrectionAddress=12A7
AFCorrectionAddress=12AD
AtmosphericPressureAddress=0
ManifoldPressureAddress=0
BoostSolenoidDutyCycleAddress=0
;;;;;;;;;;;;;;;;;;;;;;;;;;;;;;;;;;;;;;;;;;;;;;;;;;;;;;;;;;
; O2 parameters are for the Right O2 Sensor              ;
; Use 1292,12B3,12B2 for the Left O2 Sensor              ;
; O2Average is not an average, it is the current reading ;
;;;;;;;;;;;;;;;;;;;;;;;;;;;;;;;;;;;;;;;;;;;;;;;;;;;;;;;;;;
BatteryVoltageMode=1
VehicleSpeedMode=1
EngineSpeedMode=1
CoolantTempMode=1
IgnitionAdvanceMode=1
AirflowSensorMode=1
EngineLoadMode=1
ThrottlePositionMode=1
InjectorPulseWidthMode=0
ISUDutyValveMode=1
O2AverageMode=1
O2MinimumMode=-1
O2MaximumMode=-1
KnockCorrectionMode=1
AFCorrectionMode=1
AtmosphericPressureMode=0
ManifoldPressureMode=-1
BoostSolenoidDutyCycleMode=-1
;;;;;;;;;;;;;;;;;;;;;;;;;;;;;;;;;;;;;;;;;;;;;;;;;;;;;;;;;;;;;;;;;;;;;;;;;;;;;;;;;;;;;;;

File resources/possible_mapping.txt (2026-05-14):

Mode	Address	Parameter	Formula
F00	8C3D-8C3F	ROM ID NUMBER "YEAR"	See "ROM Images"
F01	102F	BATTERY VOLTAGE	volts=value*0.08
F02	1071	VEHICLE SPEED (mph)	mph=value*1.25
F03	1071	VEHICLE SPEED (km/h)	km/h=value*2
F04	106F	ENGINE SPEED	rpm=value*25
F05	1185	WATER TEMP (F)	tempF=(value-82)*9/5
F06	1185	WATER TEMP (C)	tempC=value-50
F07	10A2	IGNITION TIMING	advance=value
F08	1283	AIRFLOW SENSOR	airflow%=(value*100)/255
F09	1282	LOAD DATA	load=value
F10	128C	THROTTLE POSITION SENSOR	throttle%=(value*100)/255
F11	1280	INJECTOR PULSE WIDTH	msec=value*256/1000
F12	129D	BY-PASS AIR CONTROL	duty%=(value*100)/255
F13	1291	02 RIGHT HAND	mV=value*5000/512
F14	1292	02 LEFT HAND	mV=value*5000/512
F15	12B0	02 R MAX	mV=value*5000/256
F16	12B1	02 R MIN	mV=value*5000/256
F17	12B2	02 L MAX	mV=value*5000/256
F18	12B3	02 L MIN	mV=value*5000/256
F19	1097	AFR CORRECTION 1	afc=value-128
F20	109F	AFR CORRECTION 2	afc=value-128
F21	12A7	KNOCK CORRECTION	correction=value
F22	12A5	CANISTER PURGE CONTROL	duty%=(value*100)/255
F23	125F	ATMOSPHERIC PRESSURE	 
FB0	1026-1029	DIAG. READ	See "Reading Error Codes"
FB1	12B9-12BC	DIAG. MEMORY	See "Reading Error Codes"

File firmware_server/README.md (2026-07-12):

# firmware_server

The end-user USB recovery flasher: a static page deployed to GitHub Pages.
No Python, no backend — just static files.

## Layout

```
flasher/            static site (deployed to GitHub Pages)
  index.html          USB flasher (desktop Chrome/Edge) with a version dropdown
  versions.json       the list of available firmware versions (edit per release)
firmware/           generated release images (git-ignored, staged for Releases)
  firmware.bin        app image      (OTA: pulled by the "Update now" button)
  filesystem.bin      LittleFS / PWA (OTA: pulled by the "Update now" button)
  factory.bin         full flash     (USB recovery)
```

`index.html` reads `versions.json` and, for the selected version, flashes that
version's `factory.bin` (ESP Web Tools). GitHub release assets aren't served
with CORS headers, so `pages.yml` mirrors each listed version's `factory.bin`
onto the Pages origin (`fw/<tag>-factory.bin`) at deploy time. The `firmware/`
images are **generated** by `../firmware/build_release.sh` and published to the
Release by CI — never committed.

## Publishing a new version

1. `cd ../firmware && ./build_release.sh` (optional local check).
2. Tag + push: `git tag v0.5 && git push origin v0.5` → `release.yml` builds and
   publishes `firmware.bin` / `filesystem.bin` / `factory.bin` to the Release.
3. Add the version to `flasher/versions.json` (newest first, `latest:true` on it)
   and push to `master` → `pages.yml` redeploys the flasher.

## The three flashing methods

1. **Developer USB** — `cd ../firmware && ./upload.sh` (one combined pio command).
2. **End-user USB (recovery)** — the `flasher/` page. Hosted on Pages over HTTPS
   (Web Serial needs https or localhost).
3. **OTA (Wi-Fi)** — the device PWA's "Update now" button → `/update/pull`. The
   firmware lists the repo's releases, picks the highest version number (not
   GitHub's date-ordered `/releases/latest`), and pulls that release's
   `firmware.bin` + `filesystem.bin` by explicit tag.

## Local preview

The flasher is static, so any static file server works (Web Serial requires
https **or** localhost):

```bash
cd flasher && python -m http.server 8000   # http://localhost:8000
```

## CI / hosting (see ../.github/workflows)

- `ci.yml` — host regression tests on every push/PR.
- `pages.yml` — on every `master` push: deploy `flasher/` to GitHub Pages
  (Settings > Pages > Source = "GitHub Actions" once).
- `release.yml` — on a `v*` tag: build + package, publish the release images to
  a GitHub Release.

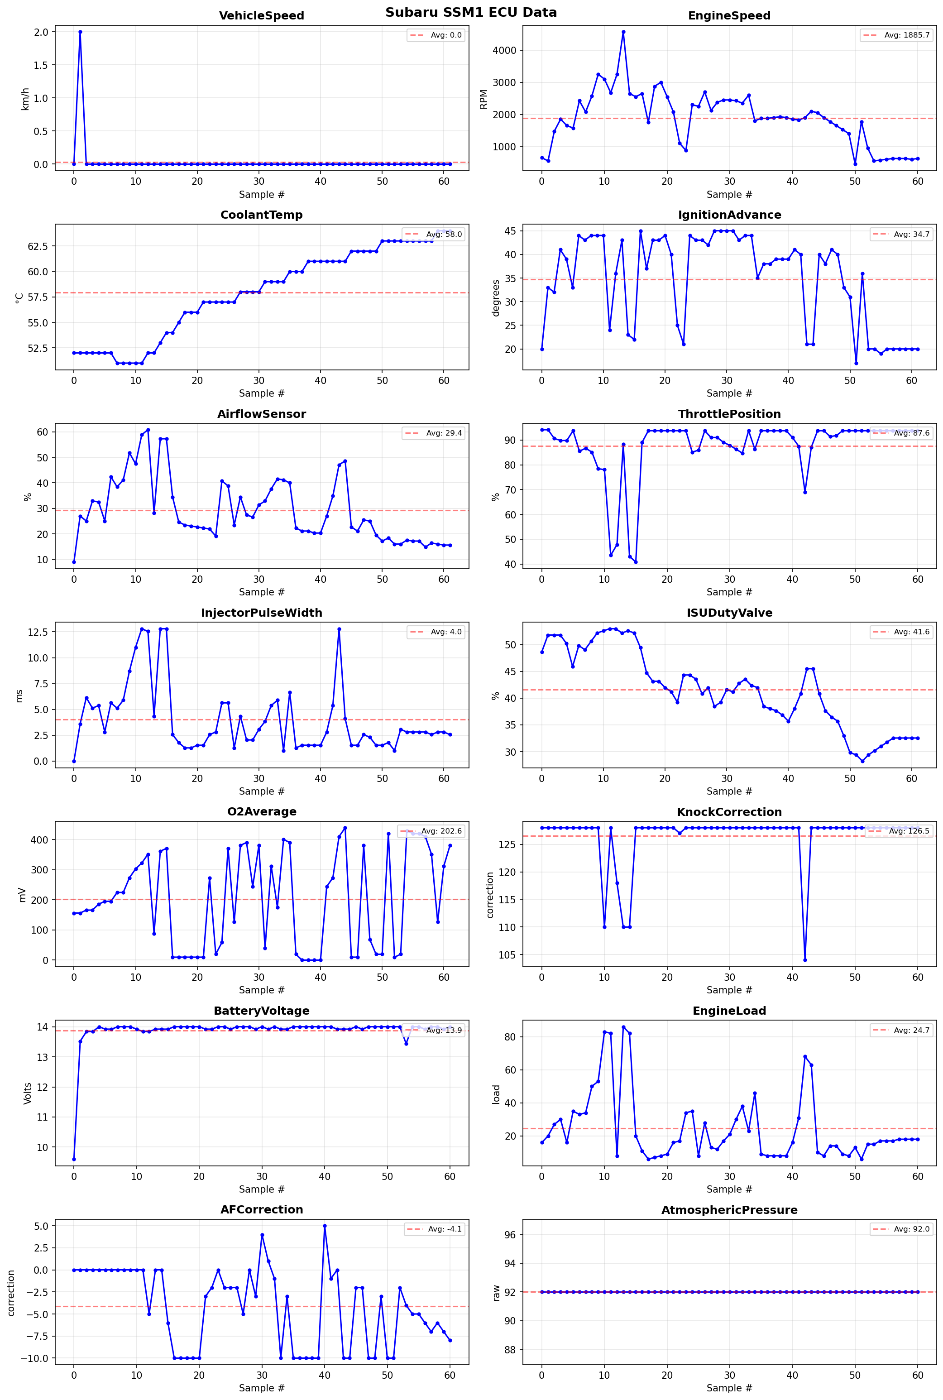
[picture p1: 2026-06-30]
resources/ecu_data_plot.png

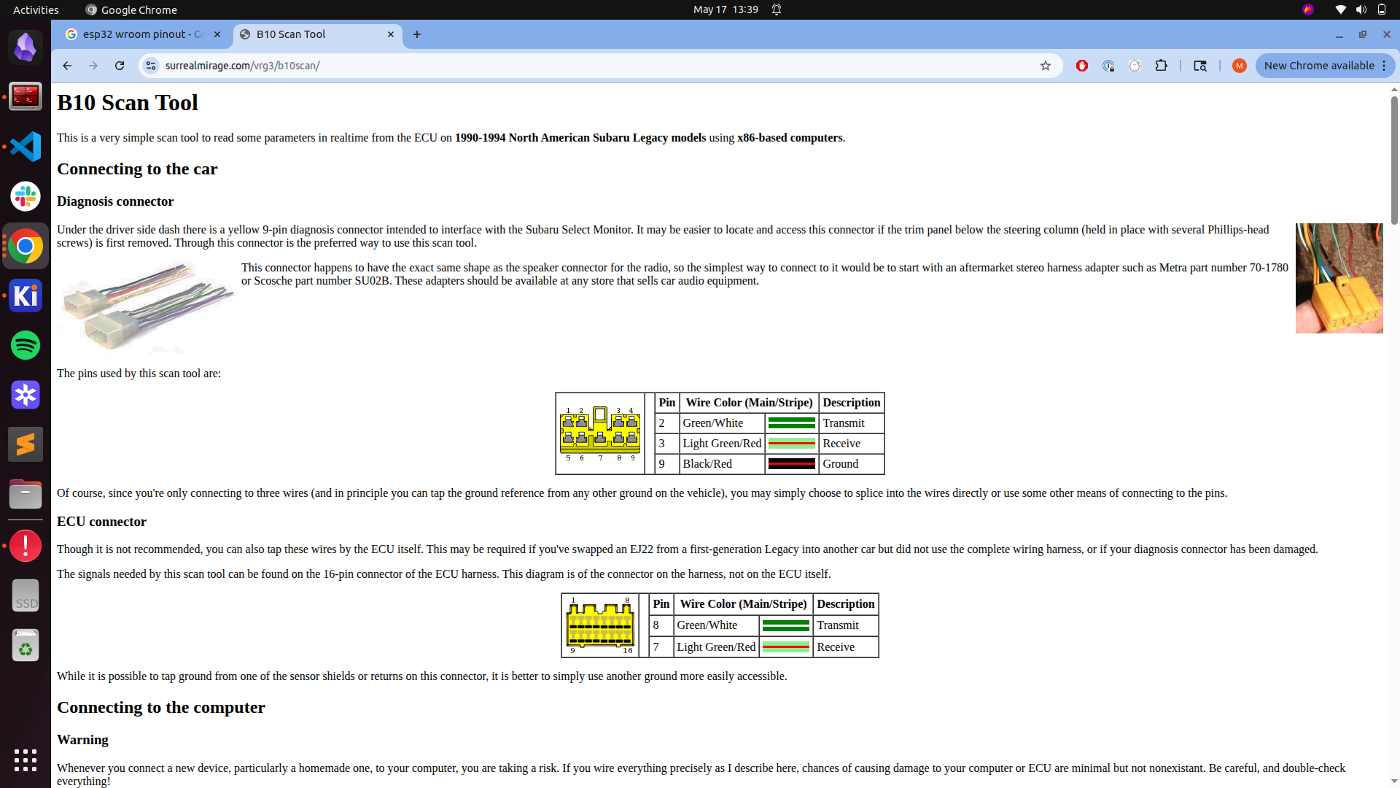
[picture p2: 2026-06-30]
resources/Screenshot from 2026-05-17 13-39-10.png

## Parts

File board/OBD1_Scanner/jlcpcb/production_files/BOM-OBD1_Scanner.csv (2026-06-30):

Comment | Designator | Footprint | LCSC | Quantity
0.1uF | C12,C14,C15,C16 | C_0603_1608Metric | C14663 | 4
0.1uF/1mOhm | C8 | C_0603_1608Metric | C14663 | 1
1.5SMCxxA | D9 | D_SMC | C522077 | 1
100 | R19,R2 | R_0603_1608Metric | C22775 | 2
100k | R1,R17,R3 | R_0603_1608Metric | C25803 | 3
10k | R10,R5 | R_0603_1608Metric | C130232 | 2
10pF | C2 | C_0603_1608Metric | C1634 | 1
10uF | C11,C13,C5,C7 | C_0603_1608Metric | C96446 | 4
10uF/1mOhm | C1 | C_0603_1608Metric | C194427 | 1
1k8 | R14 | R_0603_1608Metric | C4177 | 1
1uF | C6 | C_0603_1608Metric | C5673 | 1
1uF/1mOhm | C10 | C_0603_1608Metric | C5673 | 1
220nF/16.9mOhm | C9 | C_0603_1608Metric | C64705 | 1
24 | R12,R13 | R_0603_1608Metric | C2907132 | 2
240 | R11 | R_0603_1608Metric | C23350 | 1
24k9 | R4 | R_0603_1608Metric | C861775 | 1
39 | R15,R16,R6,R7 | R_0603_1608Metric | C23154 | 4
4.7uH/31.3mOhm | L1 | L_Changjiang_FXL0630 | C167220 | 1
47uF | C3,C4 | CP_Elec_6.3x7.7 | C3349 | 2
5k1 | R20,R21 | R_0603_1608Metric | C2907044 | 2
82 | R18 | R_0603_1608Metric | C23255 | 1
AP2112K-3.3 | U4 | SOT-23-5 | C51118 | 1
Conn_01x04 | J1 | Molex_Mini-Fit_Jr_5569-04A2_2x02_P4.20mm_Horizontal | C5362279 | 1
ESP32-S3-WROOM-1 | U1 | ESP32-S3-WROOM-1 | C2913198 | 1
LED | D6,D7,D8 | LED_0603_1608Metric_Pad1.05x0.95mm_HandSolder | C12624 | 3
LED_ARGB | D1 | LED_RGB_1210_C2890623 | C2890623 | 1
LMR33630BDDA | U2 | Texas_HSOP-8-1EP_3.9x4.9mm_P1.27mm_ThermalVias | C544370 | 1
SN74LVC1T45DBV | U3,U5 | SOT-23-6 | C7843 | 2
SS14 | D4,D5 | D_SMA | C2480 | 2
SW_Push | SW1,SW2 | SW_SPST_Panasonic_EVQPL_3PL_5PL_PT_A15 | C79172 | 2
TestPoint | TP1,TP4,TP5,TP6,TP8 | TestPoint_Loop_D2.60mm_Drill1.4mm_Beaded | C5277086 | 5
USB_C_Receptacle | J2 | USB_C_Receptacle_G-Switch_GT-USB-7010ASV | C393939 | 1
TestPoint | TP3 | TestPoint_Pad_1.5x1.5mm |  | 1

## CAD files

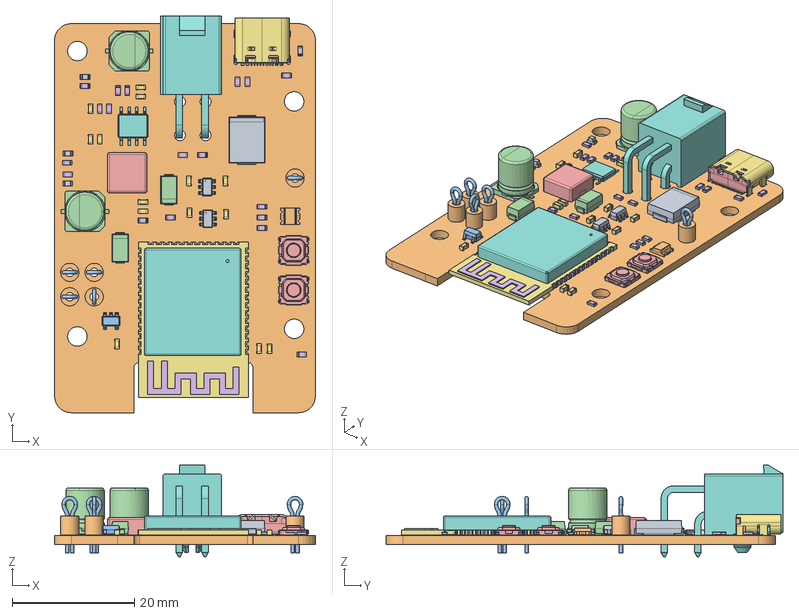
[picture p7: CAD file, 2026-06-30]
board/OBD1_Scanner/OBD1_Scanner.step
42.8 x 65.0 x 15.0 mm
LED_0603_1608Metric x 3
TestPoint_Loop_D2.60mm_Drill1.4mm_Beaded x 5
D_SMA x 2
L_Changjiang_FXL0630
R_0603_1608Metric x 19
C_0603_1608Metric x 14
SOT-23-6 x 2
LED_RGB_1210
SOT-23-5
CP_Elec_6.3x7.7 x 2
SW_SPST_Panasonic_EVQPL_3PL_5PL_PT_A15 x 2
ESP32-S3-WROOM-1
USB_C_Receptacle_GCT_USB4105-xx-A_16P_TopMnt_Horizontal
HTSOP-8-1EP_3.9x4.9mm_P1.27mm_EP2.4x3.2mm
D_SMC
OBD1_Scanner_PCB

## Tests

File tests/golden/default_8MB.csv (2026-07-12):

# Golden copy of the OTA partition layout the firmware is released against.
# Frozen on purpose: changing these offsets/sizes breaks OTA and up/down-grade
# between releases. test_partition_layout.py compares the live framework copy
# against this. If the framework ever changes it | that test fails on purpose.
# Name | Type | SubType | Offset | Size | Flags
nvs | data | nvs | 0x9000 | 0x5000
otadata | data | ota | 0xe000 | 0x2000
app0 | app | ota_0 | 0x10000 | 0x330000
app1 | app | ota_1 | 0x340000 | 0x330000
spiffs | data | spiffs | 0x670000 | 0x180000
coredump | data | coredump | 0x7F0000 | 0x10000

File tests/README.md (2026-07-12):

# Regression tests

Layers of the test pyramid that guard the firmware release contracts.

## Layer 0 — host contract tests (no hardware) — `pytest`

Lock the release contracts that let any version flash/update any other:

- `test_partition_layout.py` — OTA partition offsets/sizes are frozen (golden copy).
- `test_api_contract.py` — `/update/*` endpoints, `/status` keys, rollback wiring.
- `test_image_sizes.py` — built app/fs fit their partitions (skips if not built).
- `test_release_contract.py` — `versions.json` sanity + the asset filenames agree
  across the firmware OTA, `build_release.sh`, and `release.yml`.

Run:

```bash
cd <repo root>
../venv/bin/python -m pytest tests/ -q      # or: python -m pytest tests/
```

CI-friendly — no board required. `test_image_sizes.py` needs
`firmware/build_release.sh` to have run.

## Layer 1 — native unit tests (no hardware) — `pio test`

Pure firmware logic compiled + unit-tested natively with Unity (no board, no
toolchain download):

- `test_version_compare` — `include/version_compare.h`, the semver ordering that
  picks the highest release version (the logic behind the OTA update check).

```bash
cd firmware && pio test -e native
```

## Layers 4–5 — hardware round-trip — `hil_roundtrip.py`

Needs a real device on the **OBD1_Scanner** AP with USB plugged in (Wi-Fi + USB
are independent). On Linux, `--wifi PASSWORD` auto-joins via `nmcli` and restores
your previous network afterward.

```bash
# OTA app+fs, verify reboot into the other slot + self-confirm, both ways (Layer 4)
python tests/hil_roundtrip.py --wifi subaru92
python tests/hil_roundtrip.py --skip-usb            # baseline already running

# Rollback proof: OTA an unhealthy build, expect auto-revert to baseline (Layer 5)
python tests/hil_roundtrip.py --fault-injection --skip-usb

# Reversibility across real releases: flash baseline, then OTA each older app image
python tests/hil_roundtrip.py --downgrade-matrix ~/releases/*/firmware.bin --skip-usb
```

Needs `requests` + `esptool` + `platformio` on PATH.

## CI

CI runs Layer 0 (pytest) and Layer 1 (`pio test -e native`) on every push/PR.
Hardware layers (4–5) are manual/local.

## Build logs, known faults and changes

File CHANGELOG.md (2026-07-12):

# Changelog

All notable changes to the firmware and the PWA. Each release groups changes
into a **Firmware** section (the ESP32-S3 app) and a **PWA** section (the web
console served from the device). Versions match the git tags used to cut
releases (`vX.Y`).

## v0.4 — 2026-07-12

### Firmware
- Heartbeat LED is **blue** (was green in v0.3). The color difference makes an
  over-the-air update visible: flash v0.3 (green), hit **Update now**, and the
  heartbeat turns blue once v0.4 is running.

### PWA
- No changes from v0.3.

## v0.3 — 2026-07-12

First release on the new single-firmware / stable-asset release system.
Heartbeat LED is **green**.

### Firmware
- Collapsed the two sample builds (blink-red / blink-green) into a single
  shippable firmware (`env:obd1`). Dropped the `FW_VARIANT` build identity and
  the `/status.variant` field.
- Reworked over-the-air updates: the **Update now** button pulls `firmware.bin`
  (app) and `filesystem.bin` (LittleFS/PWA) separately from the newest release
  and flashes both. Retired the `.ota` combined-container format and the
  `/update/combined` endpoint.
- The update check lists all releases and picks the **highest version number**
  itself, rather than trusting GitHub's `/releases/latest` (which orders by the
  release's creation date and can point at the wrong version). The pull then
  fetches that version's assets by explicit tag.
- Release assets now have stable names (`firmware.bin`, `filesystem.bin`,
  `factory.bin`); the git tag carries the version.

### PWA
- Removed the manual `.ota`/`.bin` upload cards entirely; updating is the
  one-button internet **Update now** flow.
- Dropped the red/green variant color theming and the Firmware/variant status row.

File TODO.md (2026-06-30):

- LED startup test. Blink each one solid for .25seconds
- standard environment in .ini file, then add what ever unique things are there for sim. 
- wifi ota update when connected to the wifi
- add gauges and graphs to the flask app
- mpg calculation
- 0-60 timer
- flask mode for showing iphone view

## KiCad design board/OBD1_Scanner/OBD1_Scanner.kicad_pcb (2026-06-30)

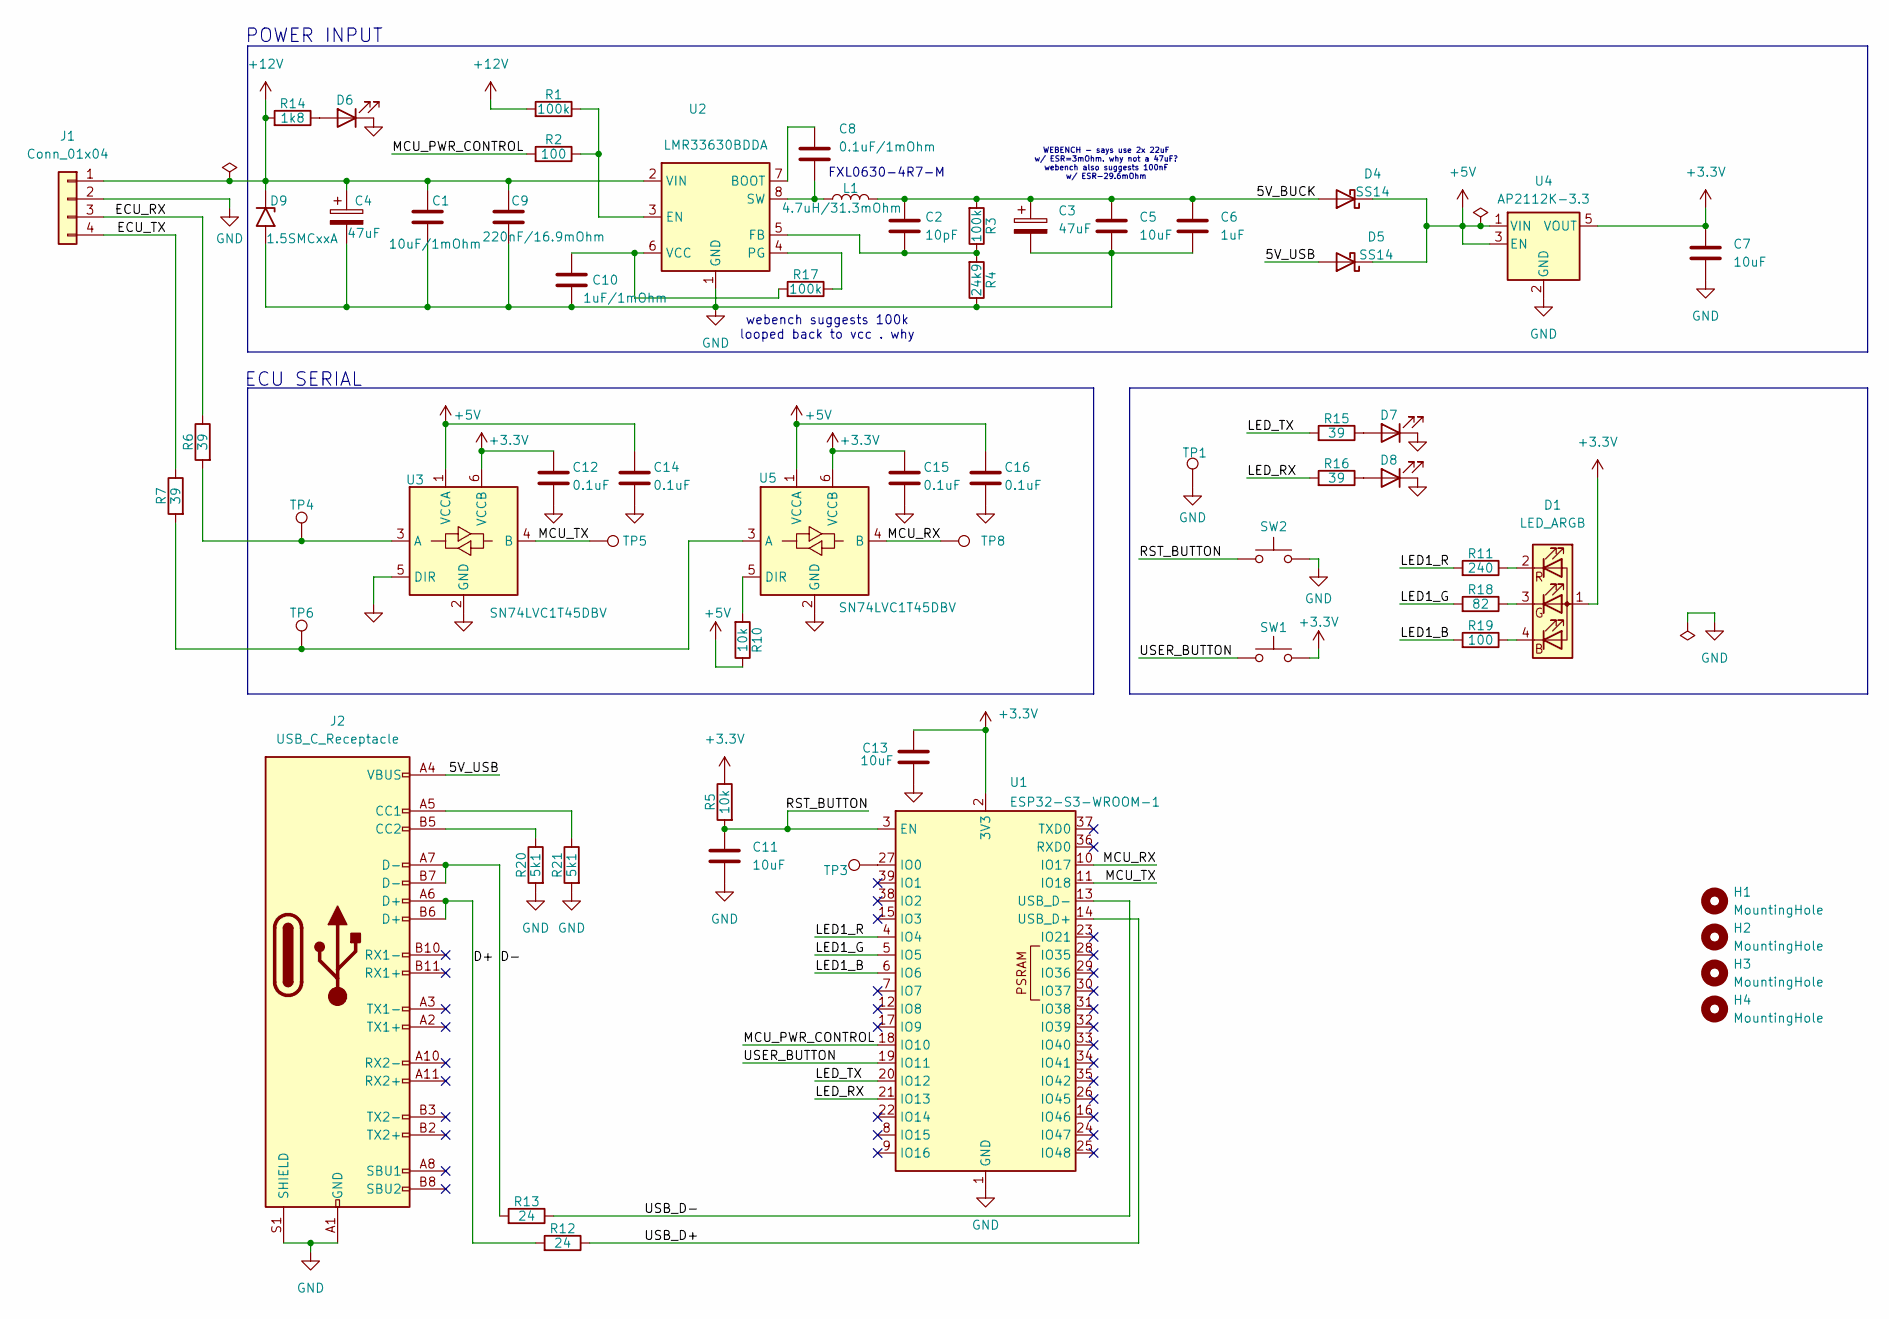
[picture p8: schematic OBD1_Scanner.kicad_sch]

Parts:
C1: 10uF/1mOhm; C_0603_1608Metric
C2: 10pF; C_0603_1608Metric
C3, C4: 47uF; CP_Elec_6.3x7.7
C5, C7, C11, C13: 10uF; C_0603_1608Metric
C6: 1uF; C_0603_1608Metric
C8: 0.1uF/1mOhm; C_0603_1608Metric
C9: 220nF/16.9mOhm; C_0603_1608Metric
C10: 1uF/1mOhm; C_0603_1608Metric
C12, C14, C15, C16: 0.1uF; C_0603_1608Metric
D1: LED_ARGB; LED_RGB_1210_C2890623
D4, D5: SS14; D_SMA
D6, D7, D8: LED; LED_0603_1608Metric_Pad1.05x0.95mm_HandSolder
D9: 1.5SMCxxA; D_SMC
H1, H2, H3, H4: MountingHole; MountingHole_3.2mm_M3_ISO7380_Pad_TopBottom
J1: Conn_01x04; Molex_Mini-Fit_Jr_5569-04A2_2x02_P4.20mm_Horizontal
J2: USB_C_Receptacle; USB_C_Receptacle_G-Switch_GT-USB-7010ASV
L1: 4.7uH/31.3mOhm; L_Changjiang_FXL0630
R1, R3, R17: 100k; R_0603_1608Metric; LCSC ^
R2, R19: 100; R_0603_1608Metric; LCSC ^
R4: 24k9; R_0603_1608Metric; LCSC ^
R5, R10: 10k; R_0603_1608Metric; LCSC ^
R6, R7, R15, R16: 39; R_0603_1608Metric; LCSC ^
R11: 240; R_0603_1608Metric; LCSC ^
R12, R13: 24; R_0603_1608Metric; LCSC ^
R14: 1k8; R_0603_1608Metric; LCSC ^
R18: 82; R_0603_1608Metric; LCSC ^
R20, R21: 5k1; R_0603_1608Metric; LCSC ^
SW1, SW2: SW_Push; SW_SPST_Panasonic_EVQPL_3PL_5PL_PT_A15
TP1, TP4, TP5, TP6, TP8: TestPoint; TestPoint_Loop_D2.60mm_Drill1.4mm_Beaded
TP3: TestPoint; TestPoint_Pad_1.5x1.5mm
U1: ESP32-S3-WROOM-1
U2: LMR33630BDDA; Texas_HSOP-8-1EP_3.9x4.9mm_P1.27mm_ThermalVias
U3, U5: SN74LVC1T45DBV; SOT-23-6
U4: AP2112K-3.3; SOT-23-5

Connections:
+3.3V: C7.1, C12.1, C13.1, C15.1, D1.1 (A), R5.2, SW1.2, U1.2 (3V3), U3.6 (VCCB), U4.5 (VOUT), U5.6 (VCCB)
+5V: C14.1, C16.1, D4.1 (K), D5.1 (K), R10.2, U3.1 (VCCA), U4.1 (VIN), U4.3 (EN), U5.1 (VCCA)
+12V: C1.1, C4.1, C9.1, D9.1 (A1), J1.1, R1.1, R14.1, U2.2 (VIN)
/5V_BUCK: C2.1, C3.1, C5.1, C6.1, D4.2 (A), L1.2, R3.1
/5V_USB: D5.2 (A), J2.A4 (VBUS), J2.A9 (VBUS), J2.B4 (VBUS), J2.B9 (VBUS)
/D+: J2.A6 (D+), J2.B6 (D+), R12.1
/D-: J2.A7 (D-), J2.B7 (D-), R13.1
/ECU_RX: J1.3, R6.2
/ECU_TX: J1.4, R7.2
/LED1_B: R19.1, U1.6 (IO6)
/LED1_G: R18.1, U1.5 (IO5)
/LED1_R: R11.1, U1.4 (IO4)
/LED_RX: R16.1, U1.21 (IO13)
/LED_TX: R15.1, U1.20 (IO12)
/MCU_PWR_CONTROL: R2.1, U1.18 (IO10)
/MCU_RX: TP8.1, U1.10 (IO17), U5.4 (B)
/MCU_TX: TP5.1, U1.11 (IO18), U3.4 (B)
/RST_BUTTON: C11.1, R5.1, SW2.1, U1.3 (EN)
/USB_D+: R12.2, U1.14 (USB_D+)
/USB_D-: R13.2, U1.13 (USB_D-)
/USER_BUTTON: SW1.1, U1.19 (IO11)
GND: C1.2, C3.2, C4.2, C5.2, C6.2, C7.2, C9.2, C10.2, C11.2, C12.2, C13.2, C14.2, C15.2, C16.2, D6.1 (K), D7.1 (K), D8.1 (K), D9.2 (A2), J1.2, J2.A1 (GND), J2.A12 (GND), J2.B1 (GND), J2.B12 (GND), J2.S1 (SHIELD), R4.2, R20.1, R21.1, SW2.2, TP1.1, U1.1 (GND), U1.40 (GND), U1.41 (GND), U2.1 (GND), U2.9 (GND), U3.2 (GND), U3.5 (DIR), U4.2 (GND), U5.2 (GND)
unnamed: D1.4 (BK), R19.2
unnamed: D1.3 (GK), R18.2
unnamed: D1.2 (RK), R11.2
unnamed: D6.2 (A), R14.2
unnamed: D7.2 (A), R15.2
unnamed: D8.2 (A), R16.2
unnamed: J2.A5 (CC1), R21.2
unnamed: J2.B5 (CC2), R20.2
unnamed: TP3.1, U1.27 (IO0)
unnamed: C8.1, U2.7 (BOOT)
unnamed: R1.2, R2.2, U2.3 (EN)
unnamed: C2.2, R3.2, R4.1, U2.5 (FB)
unnamed: R17.2, U2.4 (PG)
unnamed: C8.2, L1.1, U2.8 (SW)
unnamed: C10.1, R17.1, U2.6 (VCC)
unnamed: R6.1, TP4.1, U3.3 (A)
unnamed: R7.1, TP6.1, U5.3 (A)
unnamed: R10.1, U5.5 (DIR)

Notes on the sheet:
webench suggests 100k looped back to vcc . why
ECU SERIAL
POWER INPUT
FXL0630-4R7-M
WEBENCH - says use 2x 22uF w/ ESR=3mOhm. why not a 47uF? webench also suggests 100nF w/ ESR-29.6mOhm

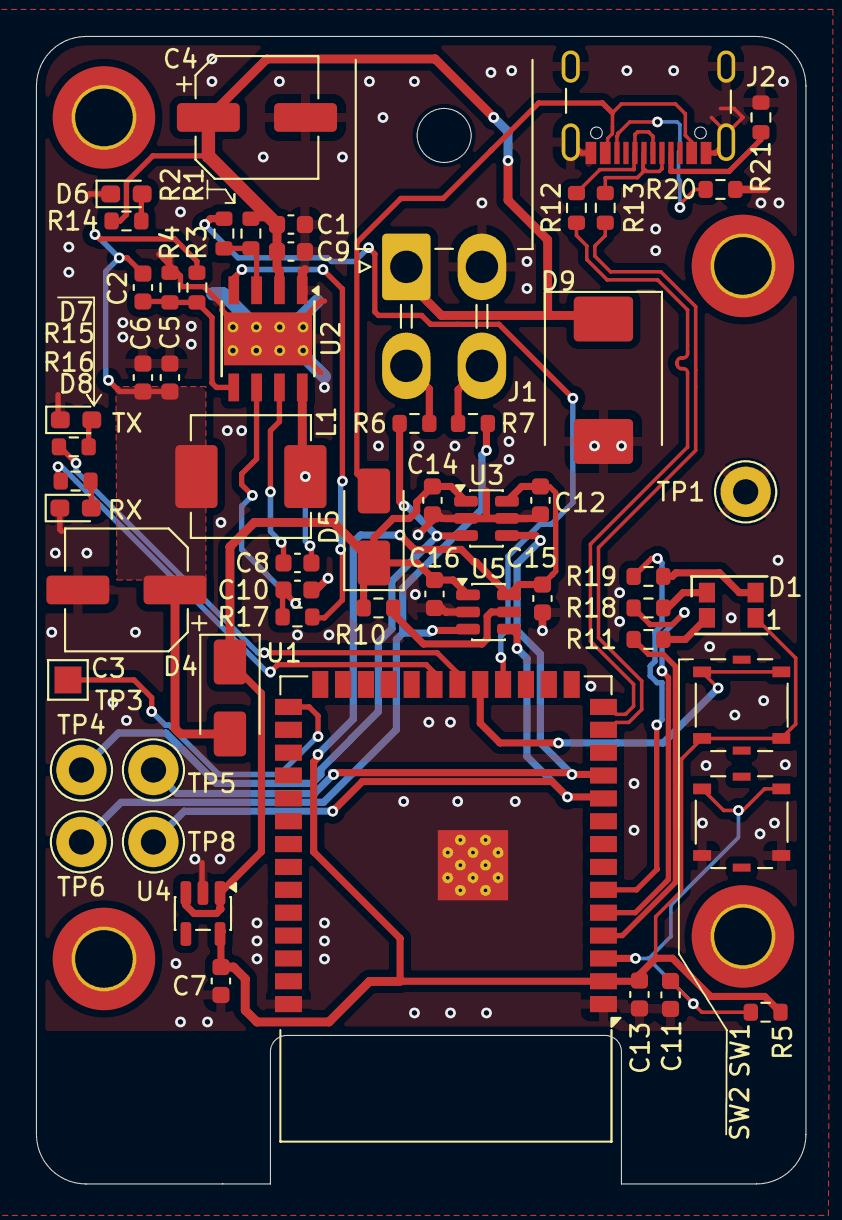
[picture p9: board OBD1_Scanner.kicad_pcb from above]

Board: 2 copper layers, 42.8 x 63.8 mm, 62 parts (0 on the bottom side), 40 nets.

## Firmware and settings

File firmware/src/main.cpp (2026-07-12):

//=============================================================================
// OBD1 Scanner — framework skeleton
//
// Bare-minimum RTOS structure to build on:
//   - blinkTask : status-LED heartbeat (proof the scheduler is alive), core 1.
//   - netTask   : AP + HTTP/WebSocket server + OTA update, core 0.
//
// Upload firmware & PWA:
//   USB : ./upload.sh              (firmware via esptool + LittleFS via uploadfs)
//   WiFi: join AP "OBD1_Scanner", open http://obd1.local, use the OTA form,
//         or POST a .bin to /update/firmware or /update/filesystem.
//=============================================================================
#include <Arduino.h>
#include <esp_ota_ops.h>
#include "version.h"
#include "pin_defs.h"
#include "web_server.h"

// Status-LED heartbeat color.
#define BLINK_LED LED_BLUE

// Common-anode RGB helper: `on` lights the color (drives the pin LOW).
static inline void ledWrite(uint8_t pin, bool on) {
  digitalWrite(pin, on ? RGB_ON : RGB_OFF);
}

// Heartbeat: a short blink ~1 Hz on the build-selected color. Runs on core 1,
// fully independent of the network stack, so a visible pulse means the RTOS
// scheduler is healthy.
static void blinkTask(void* pv) {
  const uint8_t leds[] = {LED_RED, LED_GREEN, LED_BLUE};
  for (uint8_t p : leds) { pinMode(p, OUTPUT); ledWrite(p, false); }

  for (;;) {
    ledWrite(BLINK_LED, true);
    vTaskDelay(pdMS_TO_TICKS(80));
    ledWrite(BLINK_LED, false);
    vTaskDelay(pdMS_TO_TICKS(920));
  }
}

// Network: owns the (potentially blocking) WiFi/HTTP/OTA work on core 0, off
// the core running the heartbeat.
static void netTask(void* pv) {
  WebServerApp.begin();
  for (;;) {
    WebServerApp.loop();
    vTaskDelay(pdMS_TO_TICKS(2));
  }
}

// OTA rollback (bootloader rollback is enabled in this core). A freshly-OTA'd
// image boots in PENDING_VERIFY and must confirm itself healthy. If it never
// confirms and the device later resets, the bootloader automatically reverts to
// the previous slot — we do NOT force that reboot ourselves in normal builds,
// because on a fresh flash the other slot may be empty and a self-reboot would
// loop forever. A plain USB/factory flash isn't on probation, so this no-ops.
static void confirmHealthIfPending() {
  static bool handled = false;
  if (handled) return;

  const esp_partition_t* running = esp_ota_get_running_partition();
  esp_ota_img_states_t st;
  if (!running || esp_ota_get_state_partition(running, &st) != ESP_OK ||
      st != ESP_OTA_IMG_PENDING_VERIFY) {
    handled = true;  // not on probation — nothing to confirm
    return;
  }

#ifdef FORCE_UNHEALTHY
  // Fault-injection build (env:badhealth) ONLY: never confirm, and after
  // a grace period actively roll back to prove auto-revert works. The HIL test
  // guarantees a valid previous slot, so this can't loop. Never ship this.
  if (millis() > 8000) {
    Serial.println("[ota] (test) forcing rollback to previous image");
    esp_ota_mark_app_invalid_rollback_and_reboot();  // does not return
  }
#else
  // Normal build: confirm once the network stack is up; otherwise just keep
  // running unconfirmed (safe — no self-reboot, so it can never loop).
  if (WebServerApp.ok()) {
    esp_ota_mark_app_valid_cancel_rollback();
    Serial.println("[ota] new image confirmed healthy — rollback cancelled");
    handled = true;
  }
#endif
}

void setup() {
  Serial.begin(DEBUG_BAUD);
  delay(300);
  Serial.printf("\n%s %s (%s)\nbuilt %s\n",
                FW_NAME, FW_VERSION, FW_GIT_COMMIT, FW_BUILD_DATE);

  xTaskCreatePinnedToCore(blinkTask, "blink", 2048, nullptr, 1, nullptr, 1);
  // 16 KB stack: the internet pull-OTA does a TLS handshake (mbedTLS) which
  // needs more headroom than the default 8 KB.
  xTaskCreatePinnedToCore(netTask,   "net",  16384, nullptr, 1, nullptr, 0);
}

void loop() {
  // All work happens in tasks; the loop just runs the rollback health check.
  confirmHealthIfPending();
  vTaskDelay(pdMS_TO_TICKS(1000));
}

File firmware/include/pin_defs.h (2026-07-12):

#ifndef PIN_DEFS_H
#define PIN_DEFS_H

#include <Arduino.h>

//=============================================================================
// Pin Definitions  (ESP32-S3-WROOM-1 on the OBD1_Scanner board)
//=============================================================================

// Status RGB LED (LED1). Pins from the KiCad schematic nets LED1_R/G/B.
// NOTE: do NOT use GPIO 26-32 on the ESP32-S3 — they are wired to the internal
// SPI flash/PSRAM and driving them causes a flash watchdog reset.
static const uint8_t LED_GREEN = 4;   // IO4  (LED1_R)
static const uint8_t LED_BLUE  = 5;   // IO5  (LED1_G)
static const uint8_t LED_RED   = 6;   // IO6  (LED1_B)

// The RGB LED is COMMON-ANODE: the common pin sits at 3.3V, so a color lights
// when its GPIO is driven LOW (sinks current). HIGH = off.
static const uint8_t RGB_ON  = LOW;
static const uint8_t RGB_OFF = HIGH;

// TX/RX activity LEDs (nets LED_TX / LED_RX). Cathode to GND -> ACTIVE-HIGH.
static const uint8_t LED_TX_PIN = 12; // IO12 (LED_TX)
static const uint8_t LED_RX_PIN = 13; // IO13 (LED_RX)

//=============================================================================
// Serial
//=============================================================================
static const uint32_t DEBUG_BAUD = 115200;  // USB debug serial

#endif // PIN_DEFS_H

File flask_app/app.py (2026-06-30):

#!/usr/bin/env python3
"""
Subaru SSM1 ECU Live Monitor - Flask Backend
Reads data from ESP32 over WiFi or serial and serves it via WebSocket
Now with Trouble Code (DTC) support
"""

import os
import re
import json
import threading
import time
import argparse
import requests
from collections import deque
from flask import Flask, render_template, jsonify, request
from flask_socketio import SocketIO
import serial
import serial.tools.list_ports

app = Flask(__name__)
app.config['SECRET_KEY'] = 'subaru_ssm1_secret'
socketio = SocketIO(app, cors_allowed_origins="*", async_mode='threading')

# Teensy serial port - uses udev symlink
TEENSY_PORT = '/dev/teensy'

# Conversion formulas from b10scan.asm (jecs2 for 1992 NA)
CONVERSIONS = {
    'BatteryVoltage': {'formula': lambda v: v * 0.08, 'unit': 'V', 'min': 10, 'max': 16},
    'VehicleSpeed': {'formula': lambda v: v * 1.25, 'unit': 'mph', 'min': 0, 'max': 180},
    'EngineSpeed': {'formula': lambda v: v * 25, 'unit': 'RPM', 'min': 0, 'max': 8000},
    'CoolantTemp': {'formula': lambda v: v * 1.8 - 58, 'unit': '°F', 'min': -40, 'max': 280},
    'IgnitionAdvance': {'formula': lambda v: v, 'unit': '°BTDC', 'min': 0, 'max': 60},
    'AirflowSensor': {'formula': lambda v: v * 0.02, 'unit': 'V', 'min': 0, 'max': 5},
    'EngineLoad': {'formula': lambda v: v, 'unit': '', 'min': 0, 'max': 255},
    'ThrottlePosition': {'formula': lambda v: v * 0.02, 'unit': 'V', 'min': 0, 'max': 5},
    'InjectorPulseWidth': {'formula': lambda v: v * 0.256, 'unit': 'ms', 'min': 0, 'max': 65},
    'ISUDutyValve': {'formula': lambda v: (v * 100) / 255, 'unit': '%', 'min': 0, 'max': 100},
    'O2Average': {'formula': lambda v: v * 0.02, 'unit': 'V', 'min': 0, 'max': 5},
    'KnockCorrection': {'formula': lambda v: (v - 128) * 0.25, 'unit': '°', 'min': -32, 'max': 32},
    'AFCorrection': {'formula': lambda v: (v - 128) / 1.28, 'unit': '%', 'min': -100, 'max': 100},
    'AtmosphericPressure': {'formula': lambda v: v * 8, 'unit': 'torr', 'min': 500, 'max': 800},
    'InputSwitches': {'formula': lambda v: v, 'unit': '', 'min': 0, 'max': 255},
    'IOSwitches': {'formula': lambda v: v, 'unit': '', 'min': 0, 'max': 255},
}

# DTC code descriptions (from b10scan.asm)
DTC_DESCRIPTIONS = {
    '11': 'Crank Position Sensor',
    '12': 'Starter Switch',
    '13': 'Cam Position Sensor',
    '14': 'Injector #1',
    '15': 'Injector #2',
    '16': 'Injector #3',
    '17': 'Injector #4',
    '21': 'Coolant Temperature Sensor',
    '22': 'Knock Sensor',
    '23': 'MAF Sensor',
    '24': 'IAC Valve',
    '31': 'Throttle Position Sensor',
    '32': 'Oxygen Sensor',
    '33': 'Vehicle Speed Sensor',
    '35': 'Purge Solenoid',
    '41': 'Fuel Trim',
    '42': 'Idle Switch',
    '44': 'Wastegate Control (Turbo)',
    '45': 'Barometric Pressure',
    '49': 'Wrong MAF Installed',
    '51': 'Neutral Switch',
    '52': 'Park Switch',
}

# Data storage - keep last 100 samples for each parameter
MAX_HISTORY = 100
data_history = {param: deque(maxlen=MAX_HISTORY) for param in CONVERSIONS}
current_values = {param: None for param in CONVERSIONS}
connection_status = {'connected': False, 'port': None, 'error': None}

# DTC storage
dtc_data = {
    'active': [],
    'stored': [],
    'lastRead': None,
    'reading': False
}

# Serial connection
ser = None
serial_thread = None
running = False

# WiFi mode configuration
ESP32_IP = "192.168.4.1"  # Default ESP32 AP IP
ESP32_DATA_URL = f"http://{ESP32_IP}/data"
wifi_mode = False  # Set via command line


def wifi_reader():
    global running, connection_status
    
    while running:
        try:
            response = requests.get(ESP32_DATA_URL, timeout=2)
            if response.status_code == 200:
                data = response.json()
                
                if not connection_status['connected']:
                    connection_status = {'connected': True, 'port': f'WiFi ({ESP32_IP})', 'error': None}
                    socketio.emit('connection_status', connection_status, namespace='/')
                    print(f"Connected to ESP32 at {ESP32_IP}")
                
                # Process parameters
                if 'params' in data:
                    for param in data['params']:
                        param_name = param.get('name')
                        raw_value = param.get('raw')
                        
                        if param_name and param_name in CONVERSIONS and raw_value is not None:
                            conv = CONVERSIONS[param_name]
                            converted_value = conv['formula'](raw_value)
                            
                            timestamp = time.time()
                            data_history[param_name].append({
                                'time': timestamp,
                                'value': converted_value,
                                'raw': raw_value
                            })
                            current_values[param_name] = {
                                'value': converted_value,
                                'raw': raw_value,
                                'unit': conv['unit'],
                                'min': conv['min'],
                                'max': conv['max']
                            }
                            
                            emit_data = {
                                'param': param_name,
                                'value': converted_value,
                                'raw': raw_value,
                                'unit': conv['unit'],
                                'time': timestamp
                            }
                            socketio.emit('data_update', emit_data, namespace='/')
                
                # Process DTCs if present
                if 'dtc' in data:
                    for dtc in data['dtc']:
                        dtc_type = dtc.get('type', 'active').lower()
                        code = dtc.get('code', '')
                        desc = dtc.get('desc', '')
                        
                        if dtc_type == 'active':
                            if not any(d['code'] == code for d in dtc_data['active']):
                                dtc_data['active'].append({'code': code, 'description': desc})
                        else:
                            if not any(d['code'] == code for d in dtc_data['stored']):
                                dtc_data['stored'].append({'code': code, 'description': desc})
                    
                    dtc_data['lastRead'] = time.time()
                    socketio.emit('dtc_update', dtc_data, namespace='/')
                
            time.sleep(0.2)  # Poll every 200ms
            
        except requests.exceptions.RequestException as e:
            if connection_status['connected']:
                connection_status = {'connected': False, 'port': None, 'error': str(e)}
                socketio.emit('connection_status', connection_status, namespace='/')
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

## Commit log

2026-07-12 Framework: RTOS skeleton, 3 flashing methods, OTA rollback, test pyramid
    Firmware (firmware/):
    - FreeRTOS blink heartbeat + network tasks; two sample builds (blink_red/green)
    - version.h (git-stamped), pin_defs; AP + HTTP/WebSocket server + /status
    - OTA: /update/firmware, /update/filesystem, and a combined .ota container
    parsed by a pure, unit-tested module (ota_container.h)
    - Safe bootloader-backed OTA rollback (normal builds never self-reboot)
    - default_8MB.csv (two OTA slots + LittleFS); extends-based platformio envs
    Three flashing methods (all verified on hardware):
    - Developer USB: upload.sh (one combined pio command)
    - End-user USB: ESP Web Tools flasher (firmware_server/flasher/,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
    [default_8MB.csv]
2026-07-12 Internet OTA: AP+STA Wi-Fi provisioning + pull-from-GitHub updates
    Firmware:
    - AP+STA mode: keeps hosting OBD1_Scanner AP and joins home Wi-Fi (STA).
    Credentials saved to NVS; POST /wifi to set them; /status reports STA state.
    - GET /update/check: compares FW_VERSION to the latest GitHub release tag.
    - POST /update/pull: downloads this variant's .ota from the latest release over
    HTTPS and flashes via the shared ota::Parser (applyOtaStep refactor), reboots.
    TLS via setInsecure(); netTask stack bumped to 16 KB for the handshake.
    PWA: "Internet update" card — Wi-Fi setup form, STA status, Check for updates /
    Update now flow.
    Pages hub: firmware.html serves the .ota downloads + OTA pra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
    [main.cpp, web_server.cpp, web_server.h]
2026-07-12 Release system: single firmware, drop .ota, version-dropdown flasher
    Collapse the blink-red/green sample variants into one shippable firmware
    (env:obd1, green heartbeat) and drop the FW_VARIANT identity.
    OTA: the "Update now" button now pulls firmware.bin + filesystem.bin from
    the latest GitHub release and flashes both; retire the .ota combined
    container, the /update/combined endpoint, and the manual .ota download page.
    Releases publish stable-named assets (firmware.bin/filesystem.bin/factory.bin);
    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
2026-07-12 v0.4: blue heartbeat
    Change the heartbeat LED from green (v0.3) to blue so an over-the-air
    update is visually verifiable: flash v0.3 (green), hit Update now, and the
    device comes back blue.
2026-07-12 OTA: pick newest release by version (not /releases/latest); drop manual PWA upload
    The update check was trusting GitHub's /releases/latest, which orders by the
    release's created_at, not the version — so a device could see an older release
    as "latest" (v0.3 reported up-to-date while v0.4 existed). Now the firmware
    lists all releases, picks the highest vX.Y[.Z], and pulls that tag's assets
    explicitly.
    Also removes the manual firmware/app .bin upload UI from the PWA; updating is
    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
2026-07-12 tests: revive native Layer 1 + 4 more host guards; harden pages workflow_run
    - Extract semver ordering into pure include/version_compare.h; add native Unity
    test (test_version_compare) and restore the [env:native] + CI native job.
    - Host guards: CHANGELOG covers every versions.json entry; .ota combined format
    stays retired; PWA only calls endpoints the firmware registers; the forced
    rollback-reboot stays inside the FORCE_UNHEALTHY guard.
    - Point pages.yml workflow_run at the "GitHub Release" workflow name.
    [web_server.cpp]
